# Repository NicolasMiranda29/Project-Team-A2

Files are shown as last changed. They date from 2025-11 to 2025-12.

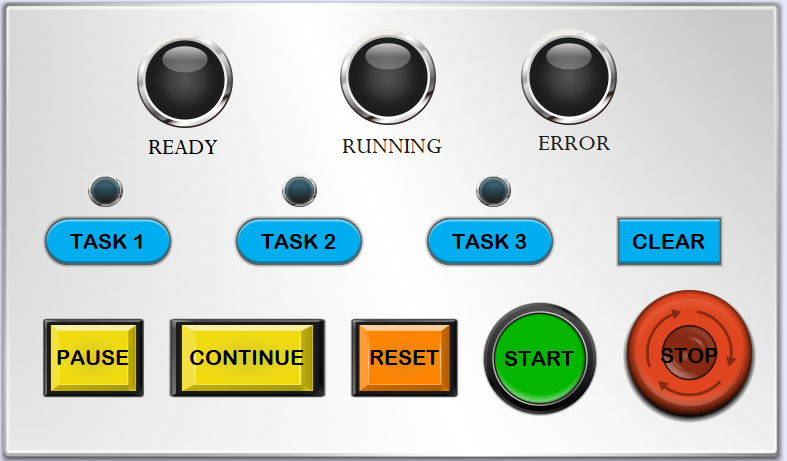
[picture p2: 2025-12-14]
INTRODUCTION TO ROBOTICS TUTORIAL/HMI/HMI_pic.png

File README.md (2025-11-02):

<h2> A2-Final Project 👩‍💻👩‍🔧👨‍💻👨‍🔧</h2>
In this section, you can see general details about two projects performed in the Robotics Lab by group A2.  
For more information, please click on the links of **"Introduction to Robotics"** and **"Introduction to Robotics Tutorial"**.

---

### Members

- **Juan Bogado** – Robot Programming  
- **Saul Ferreira** – Electrical Design  
- **Juan Chavez** – Mechanical Design  
- **Nicolas Miranda** – Documentation & Analysis

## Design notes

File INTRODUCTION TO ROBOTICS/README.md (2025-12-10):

# 🤖 PPP Robot: Port Crane-Style Prismatic Robot

This repository contains the kinematic and (optionally) dynamic models for a custom 3-DOF PPP robot with a port crane-style architecture and a two-finger gripper.

---

## 🧠 Robot Assumptions and Description

- **Type:** PPP (3 prismatic joints)
- **Structure:** Port crane-style configuration:
  - First axis (**Z**) translates along the **Y-axis** (vertical motion)
  - Second axis (**Y**) translates along the **X-axis** (horizontal motion)
  - Third axis (**X**) translates along the **Z-axis** (depth motion)

ROBOT ASSEMBLY PICTURE

**schematic diagram**



- **End-effector:** Two-finger gripper  
  > *Note: The gripper does not affect direct kinematics but may influence dynamics if its mass is modeled.*

---

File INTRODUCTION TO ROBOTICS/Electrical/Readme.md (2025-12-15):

#  **Part 4: Dynamic Analysis and Joint Torque Requirements**

Modeling Method
The dynamic modeling of the PPP Cartesian robot is carried out using a Newton–Euler formulation applied independently to each prismatic axis. Due to the orthogonal and decoupled structure of the Cartesian robot, coupling terms between axes are negligible, allowing each joint to be modeled as a translational mass subjected to inertial, gravitational, frictional, and external forces.
This approach is widely adopted in industrial gantry and Cartesian robots due to its computational simplicity and sufficient accuracy for actuator sizing

  Asumptions: 
	Payload: m_payload=5.00" kg" . \
	Extra assembly masses: m_z=6.00" kg" (Z carriage + screw + gripper), m_y=4.00" kg" (Y carriage & structure), m_x=2.00" kg" (X extras). \
	Linear maximum speeds: v_xy=0.50" m/s" (X & Y), v_z=0.20" m/s" (Z). \
	Accelerations: a_xy=1.00" " 〖"m/s" 〗^2, a_z=1.00" " 〖"m/s" 〗^2. \
	Pulley effective radius: r_p=0.020" m" (20 mm). \
	Ball-screw lead: "lead"=0.010" m/rev" (10 mm per rev). \
	Screw efficiency: η_screw=0.90. \ 
	Drive efficiency (belts/gear): η_drive=0.90. \
	Linear guide friction coefficient: μ=0.02. \
	Gravity: g=9.81" " 〖"m/s" 〗^2. \
	Safety factors: SF_XY=3.0for X/Y peaks; SF_Z=6.0for Z (holding + safety). \
\
The results of the calculations and results are shown in images

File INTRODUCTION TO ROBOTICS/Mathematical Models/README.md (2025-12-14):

## 📐 Direct Kinematic Model (DKM)

### 1. Input Variables

- `q1`: vertical displacement (Z-axis moving along Y)
- `q2`: horizontal displacement (Y-axis moving along X)
- `q3`: depth displacement (X-axis moving along Z)

### 2. End-Effector Position



### 3. Homogeneous Transformation Matrix

  

## 🔁 Inverse Kinematic Model (IKM)

Given a desired target point \((x_d, y_d, z_d)\), the required joint displacements are:



---

## 📊 Jacobian Matrix

The Jacobian relates joint velocities to the linear velocity of the end-effector:



---

## ⚙️ Dynamic Model 

For a simplified dynamic model (neglecting friction and coupling), using either the Newton-Euler or Lagrangian formulation:

Where:



### Simplified Example



## 📁 Folder Structure 
PPP_Robot/
├── README.md

├── main.m

├── gui_ppp_sim.m

├── ppp_fk.m

├── plot_ppp.m

├── animate_pick_and_place.m

├── move_to_position.m

├── ppp_dynamics.m

## Workspace


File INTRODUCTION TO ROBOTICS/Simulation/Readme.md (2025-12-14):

## Workspace


 ## Trajectory Simulation
 


 ## Path Simulation

 

# PPP Robot Simulation in MATLAB

## 📌 Project Overview
In this project, a **PPP-type robot** with a **port crane-style structure** was implemented using MATLAB.  
The project demonstrates kinematics, dynamics, visualization, and real-time control through a graphical interface.

---

## 📂 Folder Structure
The folder **`PPP_Robot_GUI`** contains the main functions:

- **`ppp_fk.m`** → Direct kinematics model  
- **`plot_ppp.m`** → Robot visualization  
- **`animate_pick_and_place.m`** → Example of a joint-space trajectory  
- **`ppp_dynamics.m`** → Simplified dynamic model  
- **`gui_ppp_sim.m`** → Graphical interface with sliders for real-time control  

---

## 🚀 Features
- Direct kinematics computation for PPP-type robot  
- Real-time visualization of robot motion  
- Example trajectory for pick-and-place tasks  
- Simplified dynamic modeling  
- Interactive GUI with sliders for intuitive control  

---

## ▶️ Usage
1. Clone or download this repository.  
2. Open MATLAB and navigate to the `PPP_Robot_GUI` folder.  
3. Run `gui_ppp_sim.m` to launch the graphical interface.  
4. Explore the other scripts for kinematics, dynamics, and trajectory examples.

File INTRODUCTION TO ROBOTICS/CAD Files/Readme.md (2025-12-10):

ROBOT ASSEMBLY PICTURE

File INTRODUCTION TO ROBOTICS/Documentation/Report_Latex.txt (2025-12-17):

\documentclass[12pt,a4paper]{report}
\usepackage{amsmath, amssymb, graphicx}
\usepackage{geometry}
\geometry{margin=2.5cm}
\usepackage{listings}
\usepackage{xcolor}
\usepackage{float}

% Estilo para mostrar código MATLAB
\lstdefinestyle{matlabstyle}{
  language=Matlab,
  backgroundcolor=\color{black!5},
  frame=single,
  framerule=0.6pt,
  basicstyle=\ttfamily\small,
  keywordstyle=\color{blue!60!black}\bfseries,
  commentstyle=\color{green!40!black}\itshape,
  stringstyle=\color{red!70!black},
  showstringspaces=false,
  breaklines=true,          % <-- corta las líneas largas automáticamente
  breakatwhitespace=true,   % <-- corta en espacios
  tabsize=2,
  captionpos=b
}

\begin{document}

\author{}
\date{}
\maketitle
\begin{titlepage}
    \centering
    \vspace*{1cm}

    % Logo institucional
    \includegraphics[width=0.8\textwidth]{Screenshot 2025-12-17 200551.png}\\[1cm] % Reemplaza 'logo.png' con el nombre de tu archivo

    % Título del proyecto
    {\Huge \textbf{PPP MANIPULATOR}}\\[0.5cm]
    {\Large Final Project Report}\\[2cm]

    % Curso y departamento
    {\large Introduction to Robotics}\\[0.3cm]
    {\large Mechanical Engineering}\\[0.3cm]
    {\large National University of Science and Technology}\\[2cm]

    % Integrantes
    {\large \textbf{Members:}}\\[0.5cm]
    {\large $\bullet$ Nicolas Miranda}\\
    {\large $\bullet$ Juan Bogado}\\
    {\large $\bullet$ Juan Chavez}\\
    {\large $\bullet$ Saul Ferreira}\\[2cm]

    % Supervisores
    {\large \textbf{Supervisors:}}\\[0.5cm]
    {\large $\bullet$ Liang Shuhao (Jason)}\\
    {\large $\bullet$ Marnel Patrick Junior Altius}\\

    \vfill
\end{titlepage}

\chapter*{Part 1: Introduction}

\section*{Application}
The difficulty of the project largely depends on its scope and intended application. Proper utilization of references and prior examples can significantly reduce the required effort, as they allow leveraging existing solutions and tested approaches. This project focuses on designing a practical, functional system that is simple enough for prototyping, yet demonstrates the core concepts effectively.

The system targets automated recycling classification using a PPP robot with a two-finger parallel gripper. It classifies small objects into three categories—metal, plastic, and paper—using cost-effective, non-vision sensors. Metal items are identified by an inductive proximity sensor, while plastic and paper are differentiated using a combination of capacitive dielectric sensing and mass measurement via a 5~kg load cell. All sensors are integrated into a fixed sensing station, which ensures stable distance, controlled grounding, low noise conditions, and repeatable force application, improving detection reliability during classification.

\section*{Robot Title and Type}
The robot, titled \textit{Automated Recycling Classifier (ARC)}, is a PPP Cartesian manipulator equipped with a two-finger parallel gripper. It employs three prismatic joints for translational motion along the X, Y, and Z axes. The use of a PPP configuration improves mechanical simplicity, supports straightforward simulation and kinematic modeling, and enables rapid prototype construction.

\section*{Problem and Task Description}
Manual sorting in recycling facilities is inefficient, inconsistent, and labor-dependent. This project automates the separation of materials by enabling the robot to pick items from the sensing zone, classify them, and deposit them into the correct bin. All detection takes place at the bench-mounted fixed sensing station, where the object's metallic response, dielectric properties, and mass are measured before sorting.

The inclusion of a load cell provides an additional physical parameter that improves robustness when distinguishing between paper and plastic, which often exhibit overlapping dielectric characteristics.

\section*{Functional and Performance Requirements}
The ARC robot must autonomously complete pick--classify--place cycles. Metal detection is executed using the inductive sensor. Plastic and paper differentiation is achieved through sensor fusion, combining capacitive dielectric measurements with mass data obtained from a 5~kg load cell mounted beneath the sensing platform. The classification process occurs at the fixed sensing station, ensuring repeatable positioning and consistent load application for reliable signal capture.

The gripper must handle objects of varying geometry without tool changes, and the system must consistently allocate objects into three output bins.

\subsection*{Performance Goals}
\begin{itemize}
    \item $\geq 90\%$ classification accuracy
    \item $\leq 5$ seconds per item cycle time
    \item End-effector repeatability within $\pm 2$~mm
    \item Support for object masses up to 5~kg, matching the load cell measurement range
\end{itemize}

\section*{Operating Environment and Constraints}
The platform is designed for benchtop operation without machine vision or external lighting. Objects must fit within the robot’s reachable workspace and be small enough for the parallel gripper. The fixed sensing station requires stable grounding, controlled contact force, and rigid mounting of the load cell to ensure accurate mass readings. Calibration of the capacitive sensor and load cell must be conducted prior to operation. Environmental factors such as humidity may influence dielectric measurements.

\subsection*{Constraints}
\begin{itemize}
    \item Inductive sensing limited exclusively to metal detection
    \item Capacitive readings sensitive to geometry, moisture, and surface area
    \item Load cell accuracy influenced by vibration and dynamic loading
    \item Limited detection capability for composite or multilayer materials
    \item Workspace constrained by PPP travel limits
\end{itemize}

\section*{Motivation}
The objective of the project is to demonstrate an affordable and compact robotic sorting system that improves sorting consistency while reducing manual labor. The integration of mass sensing enhances classification reliability without introducing complex vision systems. Automation in recycling environments reduces injuries, increases throughput stability, and enables scalable material handling at low operational cost. Institutions such as research labs, educational programs, and small recycling stations benefit directly from such a system.

\section*{Cost, Design, and Technical Constraints}
Because vision is excluded from the design, material identification relies on inductive sensing, capacitive dielectric measurement, and low-cost force-based mass estimation using a 5~kg load cell. The gripper must interface with all materials without custom attachments, and motion control must remain within safe velocity and acceleration boundaries. All decisions are made through real-time sensor readings processed by a controller.

Design considerations prioritize low-cost hardware for industrial application: inductive and capacitive sensors plus a load cell (combined cost $<$ USD~40), a PLC, and aluminum and stainless-steel structural materials. Technical limitations include sensor noise, dielectric overlap between materials, load cell drift, and inductive sensing limited to conductive metals.

\section*{Physical Assumptions Used in Modeling}
The manipulator is modeled assuming rigid-body links with negligible flex or structural deformation, enabling simplified dynamic evaluation. Prismatic joints are assumed to follow linear velocity trajectories without significant backlash or friction losses. The parallel gripper is modeled as capable of secure handling of objects up to 5~kg, without slippage under normal acceleration profiles.

The load cell is modeled as a linear elastic element with negligible hysteresis after calibration. Sensor outputs are considered deterministic once calibrated at the fixed station, allowing threshold-based classification and simple sensor fusion logic without probabilistic modeling at this stage.

\section*{Additional Considerations}
Future enhancements to the ARC platform may include machine vision for improved material recognition, machine learning-based adaptive classification combining dielectric and mass features, or increasing the number of detectable material categories. The integration of conveyor-based feed systems may also enable continuous, high-throughput sorting rather than batch-based processing. Optional end-effector-mounted force sensors could be explored to estimate mass during grasping, although this introduces additional complexity in control and dynamic compensation.

\section*{Overall Robot Diagram}
The ARC system consists of a PPP gantry structure with three linear axes, a parallel gripper, and a centralized fixed sensing station containing the inductive sensor, capacitive sensor, and a load-cell-based weighing platform. The microcontroller manages sensor fusion and classification logic, while the motion controller executes programmed trajectories. The processed items are sorted into three bins according to material classification.

\begin{figure}[H] % [h] = here, coloca la imagen en la posición actual
    \centering
    \includegraphics[width=0.8\textwidth]{Screenshot 2025-12-17 200027.png}
    \caption{CAD Drawings}
    \label{fig:robot}
\end{figure}

\begin{figure}[H]
    \centering
    \caption{Labeled robot diagram}
\end{figure}

\section*{Manipulator Workspace}
The operational workspace is defined by the gantry rails, forming a rectangular volume approximately 1000~mm $\times$ 650~mm $\times$ 410~mm. The fixed sensing station, weighing platform, and output bins are arranged within this envelope to reduce motion travel and maintain short cycle times. Objects are transported from the pick region to the sensing location, weighed and classified, and then routed to the appropriate disposal zone.

\section*{Design Specifications}
\subsection*{CAD Drawings}
All dimensions are in millimeters. The drawing scale is 4.9 relative to the robot used in this project.
\begin{figure}[H] % [h] = here, coloca la imagen en la posición actual
    \centering
    \includegraphics[width=0.8\textwidth]{Screenshot 2025-12-17 195749.png}
    \caption{CAD Drawings}
    \label{fig:robot}
\end{figure}

\begin{figure}[H] % [h] = here, coloca la imagen en la posición actual
    \centering
    \includegraphics[width=0.8\textwidth]{Screenshot 2025-12-17 195904.png}
    \caption{Cad File}
    \label{fig:robot}
\end{figure}

\chapter*{Part 2: Kinematic Structure}
\section*{Robot Joints and Kinematic Structure}
The robot is designed as a PPP manipulator, meaning it has three prismatic joints arranged orthogonally. This configuration enables simple translational motion in the three independent directions $(X, Y, Z)$, ensuring that the end-effector can reach any point within a rectangular workspace.

\subsection*{Reasoning for Design}
Three prismatic joints were selected because they provide the minimum degrees of freedom required for full translational positioning in 3D space. The absence of rotational joints simplifies kinematic equations, avoids singularities, and reduces control complexity. This structure is ideal for pick-and-place tasks, material handling, and environments where end-effector orientation is fixed or non-critical.

\section*{Joint Types, Axes, and Limits}
\begin{itemize}
    \item \textbf{Joint 1 ($q_1$):} Prismatic along the Y axis (vertical). Critical due to gravitational load. Typical limits: $q_1 \in [q_{1,\min}, q_{1,\max}]$.
    \item \textbf{Joint 2 ($q_2$):} Prismatic along the X axis (horizontal). Provides lateral positioning. Limits: $q_2 \in [q_{2,\min}, q_{2,\max}]$.
    \item \textbf{Joint 3 ($q_3$):} Prismatic along the Z axis (depth). Provides forward/backward positioning. Limits: $q_3 \in [q_{3,\min}, q_{3,\max}]$.
\end{itemize}

\section*{Forward Kinematic Model}
Frame assignments:
\begin{itemize}
    \item Base frame $\{0\}$ fixed at the origin.
    \item Frame $\{1\}$ translates along Y.
    \item Frame $\{2\}$ translates along X.
    \item Frame $\{3\}$ translates along Z.
    \item End-effector frame attached to the gripper.
\end{itemize}

\begin{figure}[H] % [h] = here, coloca la imagen en la posición actual
    \centering
    \includegraphics[width=0.8\textwidth]{Screenshot 2025-12-17 195458.png}
    \caption{Schematic Diagram}
    \label{fig:robot}
\end{figure}

The end-effector position is simply:
\[
    x = q_2, \quad y = q_1, \quad z = q_3.
\]

The homogeneous transformation from base to end-effector is:
\[
T_{0\,EE} =
\begin{bmatrix}
1 & 0 & 0 & q_2 \\
0 & 1 & 0 & q_1 \\
0 & 0 & 1 & q_3 \\
0 & 0 & 0 & 1
\end{bmatrix}.
\]

\section*{Modified DH Parameters}
Since this is a PPP robot:
\begin{itemize}
    \item All twist angles $\alpha_i = 0$.
    \item All link lengths $a_i = 0$.
    \item $\theta_i$ values are constant.
    \item $d_i$ corresponds to $q_1, q_2, q_3$.
\end{itemize}

\section*{Inverse Kinematic Model}
The IK is direct:
\[
q_1 = y_d, \quad q_2 = x_d, \quad q_3 = z_d.
\]

Joint limits must be satisfied:
\[
q_i \in [q_{i,\min}, q_{i,\max}].
\]

Velocity and acceleration limits:
\[
|\dot{q}_i| \le \dot{q}_{i,\max}, \qquad |\ddot{q}_i| \le \ddot{q}_{i,\max}.
\]

Gravity compensation on $q_1$ is recommended:
\[
F_{g,1} = m_{\mathrm{eff},1} g.
\]

\section*{Extended Inverse Kinematic (IK) Model}
For the PPP manipulator (three mutually orthogonal prismatic joints), the end-effector orientation is fixed and motion is purely translational. The IK solution is direct and exact.

\subsection*{Analytical Solution}
Given a desired Cartesian target position $(x_d, y_d, z_d)$ expressed in the base frame:
\[
q_1 = y_d, \qquad q_2 = x_d, \qquad q_3 = z_d.
\]
This yields an analytical, closed-form, globally valid solution with no singularities.

\subsection*{Joint Priorities and Physical Considerations}
\begin{itemize}
    \item \textbf{$q_1$ (vertical axis)}: Most critical due to gravitational load and safety. Requires smoother trajectories and torque/force considerations.
    \item \textbf{$q_2$ and $q_3$ (horizontal axes)}: Dynamically less restrictive; can sustain higher allowable velocities and accelerations.
    \item Joint priorities may be implemented through weighted objective functions in task-space or joint-space control.
\end{itemize}

\subsection*{IK Constraints}
\paragraph{Joint limits}
\[
q_1 \in [q_{1,\min}, q_{1,\max}], \qquad q_2 \in [q_{2,\min}, q_{2,\max}], \qquad q_3 \in [q_{3,\min}, q_{3,\max}].
\]
The target is feasible only if $(x_d, y_d, z_d)$ lies inside the rectangular parallelepiped defined by these limits.

\paragraph{Velocity and acceleration limits}
\[
|\dot{q}_i| \leq \dot{q}_{i,\max}, \qquad |\ddot{q}_i| \leq \ddot{q}_{i,\max}.
\]
These limits constrain the achievable trajectories during motion execution.

\paragraph{Collision and safety constraints} Avoid operating close to hard limits or obstacles; incorporate safe margins when generating trajectories.

\subsection*{Stability and Robustness Considerations}
\begin{itemize}
    \item \textbf{Filtering and anti-jitter}: Apply smoothing (e.g., low-pass filters or spline interpolation) to avoid abrupt changes caused by noise.
    \item \textbf{Soft saturations}: Use continuous saturation functions to prevent discontinuities when enforcing limits.
    \item \textbf{Task-space control stability}: Since $J$ is constant and full rank, a PID or PD controller with feedforward ensures practical stability.
    \item \textbf{Gravity compensation}: For the vertical joint,
    \[
    F_{g,1} = m_{\mathrm{eff},1} \cdot g,
    \]
    improves accuracy and reduces steady-state error.
\end{itemize}

\section*{Differential Kinematic Model}
The differential model relates joint velocities to Cartesian velocities of the end-effector.

Jacobian:
\[
J = \begin{bmatrix} 0 & 1 & 0 \\ 1 & 0 & 0 \\ 0 & 0 & 1 \end{bmatrix},
\qquad x=[x,y,z]^T,\quad q=[q_1,q_2,q_3]^T.
\]

Velocities:
\[
\dot{x} = J\, \dot{q}, \qquad \dot{q} = J^{-1}\dot{x}.
\]
Since $J$ is constant and full rank, inversion is stable.

Accelerations:
\[
\ddot{x} = J\, \ddot{q}.
\]
No $\dot{J}$ terms appear because $J$ is constant.

\subsection*{Differential Control with Priorities}
Weighted task-space mapping may be used with $W_x = \mathrm{diag}(w_x,w_y,w_z)$.

\subsection*{Limits and Stability}
Saturate $\dot{q}$ and $\ddot{q}$ to respect actuator limits. Constant full-rank $J$ ensures numerical stability.
Jacobian:
\[
J =
\begin{bmatrix}
0 & 1 & 0 \\
1 & 0 & 0 \\
0 & 0 & 1
\end{bmatrix}.
\]

Forward differential kinematics:
\[
\dot{x} = J \, \dot{q}.
\]

Inverse differential kinematics:
\[
\dot{q} = J^{-1} \dot{x}.
\]
Since $J$ is constant and full rank, the inversion is stable.

\chapter*{Part 3: Workspace Analysis}

\section*{Reachable vs Dexterous Workspace}
For the PPP robot, the reachable workspace is a rectangular parallelepiped defined by the maximum ranges of all three prismatic joints. Since the robot has no rotational joints, the end-effector orientation is fixed. Therefore, the dexterous workspace coincides with the reachable workspace, but without orientation freedom.

Analytically:
\[
x \in [0, Q_{2\max}], \quad y \in [0, Q_{1\max}], \quad z \in [0, Q_{3\max}].
\]
This produces a simple box-shaped workspace. 

\section*{Numerical Workspace Plot}
A numerical simulation confirms that the analytical workspace matches the computed workspace.

\begin{figure}[H] % [h] = here, coloca la imagen en la posición actual
    \centering
    \includegraphics[width=0.8\textwidth]{Screenshot 2025-12-17 195059.png}
    \caption{Workspace Plot}
    \label{fig:robot}
\end{figure}

\vspace{2\baselineskip} % deja 2 líneas en blanco

\section*{Jacobian-Based Singularity Identification}
The Jacobian is:
\[
J = 
\begin{bmatrix}
0 & 1 & 0 \\
1 & 0 & 0 \\
0 & 0 & 1
\end{bmatrix}.
\]
Since it is constant and full rank , no singularities occur.

\section*{Classification of Singularities}
A PPP robot has no internal singularities. Only mechanical limits at the boundaries restrict motion.

\section*{Workspace Limitations and Implications}
\begin{itemize}
  \item Rectangular workspace limited by joint ranges.
  \item No orientation freedom.
  \item Not suitable for orientation-dependent tasks.
  \item Well-suited for structured pick-and-place applications.
  \item Handling capacity depends on gripper geometry.
  \item Limited versatility due to absence of rotational DOF.
\end{itemize}

\chapter*{Part 4: Dynamic Analysis and Joint Torque Requirements}

\section*{Modeling Method}
The dynamic modeling of the PPP Cartesian robot is carried out using a Newton–Euler formulation applied independently to each prismatic axis. Due to the orthogonal and decoupled structure of the Cartesian robot, coupling terms between axes are negligible, allowing each joint to be modeled as a translational mass subjected to inertial, gravitational, frictional, and external forces.

This approach is widely adopted in industrial gantry and Cartesian robots due to its computational simplicity and sufficient accuracy for actuator sizing.

\section*{Full Dynamic Equation}
For each prismatic axis, the translational dynamic equation is expressed as:
\[
F_{\text{tot}} = m \cdot a + F_{\text{grav}} + F_{\text{fric}} + F_{\text{ext}}
\]
where:
\begin{itemize}
    \item $m$ is the equivalent moving mass including payload,
    \item $a$ is the linear acceleration,
    \item $F_{\text{grav}} = m \cdot g$ (only for the Z-axis),
    \item $F_{\text{fric}} = \mu \cdot m \cdot g$,
    \item $F_{\text{ext}}$ represents external process forces.
\end{itemize}

The required actuator torque is obtained from the total force using the drive kinematics:
\[
\tau = \frac{F_{\text{tot}} \cdot r_p}{\eta_{\text{drive}}} \quad \text{(belt-driven X and Y axes)}
\]
\[
\tau = \frac{F_{\text{tot}} \cdot L}{2\pi \cdot \eta_{\text{screw}}} \quad \text{(ball-screw-driven Z axis)}
\]
where $r_p$ is the pulley radius, $L$ is the screw lead, and $\eta$ is the transmission efficiency.

\section*{Gravity Torque Calculation (Z Axis)}
For the ball-screw lift axis:
\begin{enumerate}
    \item Moving mass: $m_Z = 11.00 \,\text{kg}$
    \item Gravity force: $F_{\text{grav}} = m_Z \cdot g = 11.00 \times 9.81 = 107.91 \,\text{N}$
    \item Acceleration force: $F_{\text{acc,Z}} = m_Z \cdot a_z = 11.00 \times 1.00 = 11.00 \,\text{N}$
    \item Total axial force: $F_{\text{tot,Z}} = 107.91 + 11.00 = 118.91 \,\text{N}$
    \item Screw torque:
    \[
    T_{\text{screw}} = \frac{F_{\text{tot,Z}} \cdot \text{lead}}{2\pi \cdot \eta_{\text{screw}}}
    = \frac{118.91 \times 0.010}{6.283 \times 0.90} \approx 0.210 \,\text{N·m}
    \]
    \item Motor torque (direct drive): $T_{\text{motor,Z}} \approx 0.210 \,\text{N·m}$
    \item Screw speed: $v_z/\text{lead} = 0.20/0.010 = 20.0 \,\text{rev/s} = 1200 \,\text{RPM}$
    \item Angular speed: $\omega = 2\pi \cdot 20.0 = 125.66 \,\text{rad/s}$
    \item Mechanical power: $P_{\text{motor,Z}} = T_{\text{motor,Z}} \cdot \omega \approx 26.4 \,\text{W}$
    \item With safety factor $SF_Z = 6$: $T_{\text{design,Z}} = 0.210 \times 6 = 1.26 \,\text{N·m}$
    \item Design-equivalent power: $P_{\text{design,Z}} = 1.26 \times 125.66 \approx 158.5 \,\text{W}$
\end{enumerate}

Thus, a servo in the 200–400 W range is appropriate for the Z axis.

\section*{Inertial Torque from Trajectory Motion (X Axis)}
For the belt-driven X axis:
\begin{enumerate}
    \item Acceleration force: $F_{\text{acc,X}} = m_X \cdot a_{xy} = 17.00 \times 1.00 = 17.00 \,\text{N}$
    \item Friction force: $F_{\text{fric,X}} = \mu \cdot m_X \cdot g = 0.02 \times (17.00 \times 9.81) = 3.34 \,\text{N}$
    \item Total force: $F_{\text{tot,X}} = 17.00 + 3.34 = 20.34 \,\text{N}$
    \item Pulley torque: $T_{\text{pulley,X}} = F_{\text{tot,X}} \cdot r_p = 20.34 \times 0.020 = 0.407 \,\text{N·m}$
    \item Motor torque: $T_{\text{motor,X}} = 0.407 / 0.90 \approx 0.452 \,\text{N·m}$
    \item Speed: $v_{xy}/(2\pi r_p) = 0.50/0.1257 \approx 3.98 \,\text{rev/s} = 238.7 \,\text{RPM}$
    \item Angular speed: $\omega = 25.0 \,\text{rad/s}$
    \item Mechanical power: $P_{\text{motor,X}} = 0.452 \times 25.0 \approx 11.3 \,\text{W}$
    \item With safety factor $SF_X = 3$: $T_{\text{peak,X}} = 0.452 \times 3 = 1.36 \,\text{N·m}$
\end{enumerate}

\section*{Inertial Torque from Trajectory Motion (Y Axis)}
For the belt-driven Y axis:
\begin{enumerate}
    \item Acceleration force: $F_{\text{acc,Y}} = m_Y \cdot a_{xy} = 15.00 \times 1.00 = 15.00 \,\text{N}$
    \item Friction force: $F_{\text{fric,Y}} = 0.02 \times (15.00 \times 9.81) = 2.94 \,\text{N}$
    \item Total force: $F_{\text{tot,Y}} = 15.00 + 2.94 = 17.94 \,\text{N}$
    \item Pulley torque: $T_{\text{pulley,Y}} = 17.94 \times 0.020 = 0.359 \,\text{N·m}$
    \item Motor torque: $T_{\text{motor,Y}} = 0.359 / 0.90 \approx 0.399 \,\text{N·m}$
    \item Speed: same as X axis, $238.7 \,\text{RPM}$, $\omega = 25.0 \,\text{rad/s}$
    \item Mechanical power: $P_{\text{motor,Y}} = 0.399 \times 25.0 \approx 9.97 \,\text{W}$
    \item With safety factor $SF_Y = 3$: $T_{\text{peak,Y}} = 0.399 \times 3 = 1.20 \,\text{N·m}$
\end{enumerate}

\section*{Payload and External Forces}
The payload mass is included in the equivalent moving mass of each axis.  
No additional external process forces are considered for pick-and-place operation.

\subsection*{Assumptions}
\begin{itemize}
    \item Payload: $m_{\text{payload}} = 5.00 \,\text{kg}$
    \item Extra assembly masses: $m_z = 6.00 \,\text{kg}$ (Z carriage + screw + gripper), $m_y = 4.00 \,\text{kg}$ (Y carriage \& structure), $m_x = 2.00 \,\text{kg}$ (X extras)
    \item Linear maximum speeds: $v_{xy} = 0.50 \,\text{m/s}$ (X \& Y), $v_z = 0.20 \,\text{m/s}$ (Z)
    \item Accelerations: $a_{xy} = 1.00 \,\text{m/s}^2$, $a_z = 1.00 \,\text{m/s}^2$
    \item Pulley effective radius: $r_p = 0.020 \,\text{m}$ (20 mm)
    \item Ball-screw lead: $\text{lead} = 0.010 \,\text{m/rev}$ (10 mm per rev)
    \item Screw efficiency: $\eta_{\text{screw}} = 0.90$
    \item Drive efficiency (belts/gear): $\eta_{\text{drive}} = 0.90$
    \item Linear guide friction coefficient: $\mu = 0.02$
    \item Gravity: $g = 9.81 \,\text{m/s}^2$
    \item Safety factors: $SF_{XY} = 3.0$ for X/Y peaks; $SF_Z = 6.0$ for Z (holding + safety)
    \item Workspace: $X = 1.000 \,\text{m}, Y = 0.610 \,\text{m}, Z = 0.410 \,\text{m}$
\end{itemize}

\subsection*{Notation \& Formulas}
\[
F_{\text{acc}} = m \cdot a, \quad
F_{\text{fric}} = \mu \cdot m \cdot g, \quad
F_{\text{tot}} = F_{\text{acc}} + F_{\text{fric}}
\]
\[
T_{\text{pulley}} = F_{\text{tot}} \cdot r_p, \quad
T_{\text{motor}} = \frac{T_{\text{pulley}}}{\eta_{\text{drive}}}
\]
\[
T_{\text{screw}} = \frac{F_{\text{tot}} \cdot \text{lead}}{2\pi \cdot \eta_{\text{screw}}}
\]
\[
\text{rev/s} = \frac{v}{2\pi r_p}, \quad \text{RPM} = \text{rev/s} \cdot 60, \quad
\omega = 2\pi \cdot \text{rev/s}
\]
\[
P = T \cdot \omega, \quad
T_{\text{design}} = T_{\text{motor}} \cdot SF
\]

\subsection*{Step-by-Step Numeric Calculations}
Masses each axis must move:
\[
m_Z = m_{\text{payload}} + m_z = 5.00 + 6.00 = 11.00 \,\text{kg}
\]
\[
m_Y = m_{\text{payload}} + m_z + m_y = 5.00 + 6.00 + 4.00 = 15.00 \,\text{kg}
\]
\[
m_X = m_{\text{payload}} + m_z + m_y + m_x = 5.00 + 6.00 + 4.00 + 2.00 = 17.00 \,\text{kg}
\]

\section*{Maximum Required Joint Torque Determination}
From Sections 4.3 and 4.4, the maximum continuous torque requirements are:
\[
T_{\text{motor,X}} = 0.452 \,\text{N·m}, \quad
T_{\text{motor,Y}} = 0.399 \,\text{N·m}, \quad
T_{\text{motor,Z}} = 0.210 \,\text{N·m}
\]

\section*{Safety Factor for Actuator Sizing}
\[
T_{\text{design}} = T_{\text{max}} \cdot SF
\]
\begin{itemize}
    \item For X and Y axis, $SF = 3$
    \item For Z axis, $SF = 6$
\end{itemize}
\[
T_{\text{design,X}} = 1.36 \,\text{N·m}, \quad
T_{\text{design,Y}} = 1.20 \,\text{N·m}, \quad
T_{\text{design,Z}} = 1.26 \,\text{N·m}
\]

\section*{Torque Tables and Plots}
\begin{table}[H] % [H] fuerza la posición exacta
\centering
\caption{Torque requirements and selected motors}
\begin{tabular}{|c|c|c|c|}
\hline
Axis & Continuous Torque (N·m) & Design Torque (N·m) & Selected Motor \\
\hline
X & 0.45 & 1.36 & 750 W servo \\
Y & 0.40 & 1.20 & 400 W servo \\
Z & 0.21 & 1.26 & 750 W servo \\
\hline
\end{tabular}
\end{table}

\begin{figure}[H] % [h] = here, coloca la imagen en la posición actual
    \centering
    \includegraphics[width=0.7\textwidth]{Screenshot 2025-12-17 192806.png}
    \caption{Torque vs. Time}
    \label{fig:robot}
\end{figure}

\begin{figure}[H] % [h] = here, coloca la imagen en la posición actual
    \centering
    \includegraphics[width=0.7\textwidth]{Screenshot 2025-12-17 193152.png}
    \caption{Speed-Torque curve.}
    \label{fig:robot}
\end{figure}

\section*{Components \& Design}

\subsection*{Main Controller}
\begin{itemize}
    \item Siemens S7-1200 PLC
    \item Model: CPU 1212C AC/DC/Relay (6ES7212-1HE40-0XB0)
    \item 8 DI, 6 DO, expandable
    \item Reliable for industrial environment
    \item Expansion for Stepper/Servo Control (PTO Outputs)
    \item Siemens Signal Board SB 1231 (if extra AI required)
    \item Siemens Pulse-train module not required → CPU1212C already supports PTO up to 100 kHz
\end{itemize}

\subsection*{Servo Motors + Drivers (PPP Axes)}
Payload 5 kg + 1 m horizontal travel requires servo motors, not steppers.
\begin{itemize}
    \item \textbf{X Axis (1 m travel)}  
    Servo motor: Delta ECMA-C20807RS (750 W, 3000 rpm)  
    Driver: Delta ASDA-B2 series (Model: ASD-B2-0721-B)  
    Transmission: HTD 5M belt, 25 mm wide OR ballscrew SFU1610
    \item \textbf{Y Axis (1 m travel)}  
    Servo motor: Delta ECMA-C20604RS (400 W)  
    Driver: Delta ASD-B2-0421-B (400 W driver)  
    Transmission: HTD 5M belt, 20–25 mm width
    \item \textbf{Z Axis (0.8–1 m vertical travel)}  
    Servo motor: Delta ECMA-C20807RS (750 W)  
    Driver: Delta ASD-B2-0721-B  
    Transmission: Ballscrew SFU1610 with BK/BF supports + linear guides
\end{itemize}

\subsection*{Linear Motion Components}
\begin{itemize}
    \item Linear Guides: Hiwin HGR20 rails (20 mm width)
    \item Blocks: HGW20CC (4 per axis)
    \item Ballscrews: SFU1610 (16 mm dia, 10 mm pitch) for Z; SFU1605 or HTD 5M belt drive for X \& Y
\end{itemize}

\subsection*{Sensors for Material Classification}
\begin{itemize}
    \item \textbf{Metal Detection}: Inductive sensor LJ12A3-4-Z/BX, PNP Normally Open, 10–30 VDC
    \item \textbf{Plastic vs Paper Detection}: Capacitive sensor LJC18A3-B-Z/BX, PNP Normally Open, 10–30 VDC
    \item \textbf{Weight Measurement}: Load cell 5 kg aluminum plate, amplifier Waveshare 0–10 V output, connected to PLC AI0
\end{itemize}

\subsection*{Gripper (Pneumatic)}
\begin{itemize}
    \item Parallel Pneumatic Gripper: SMC MHZ2-20D
    \item Solenoid Valve: SMC SY3120-5LZD-01, 24 VDC, 3-way single solenoid
    \item Pneumatic Air Preparation: SMC AF20-N02 (filter), SMC AR20-N02 (regulator)
\end{itemize}

\subsection*{Power Supply System}
\begin{itemize}
    \item For PLC, sensors, valves (24 VDC bus): Meanwell LRS-350-24, 24 V, 14.6 A
    \item For servo drives (48 VDC bus): Meanwell RSP-750-48, 48 V, 60 A
    \item For load cell amplifier: same 24 V bus (accepts 12–24 V)
\end{itemize}

\subsection*{Safety Components}
\begin{itemize}
    \item Main Breaker: Schneider GV2-ME10 (adjustable 6–10 A)
    \item Emergency Stop: Schneider XALK178 mushroom E-stop
    \item Fuses: 5×20 mm fuse holders, 3A fuse for 24V logic, 10–15A fuse for servo power input
    \item Surge \& Noise Protection: Ferrite cores on all servo cables, EMI filter Schaffner FN2070-10-06
\end{itemize}

\subsection*{Cables \& Wiring}
\begin{itemize}
    \item Servo Motor Power Cables: 4-core shielded, 2.5 mm² (750 W), 1.5 mm² (400 W), length 8–10 m per axis
    \item Encoder/Signal Cables: 6-core shielded twisted pair, 0.5–0.75 mm², 10 m per axis
    \item Sensor Cables: 3-wire shielded, 0.5 mm², 5–10 m
    \item PLC Wiring: Single core 0.75 mm² for DO/DI and 24V distribution
\end{itemize}

\subsection*{Electrical Enclosure Components}
\begin{itemize}
    \item Metal enclosure 600×400×200 mm (steel)
    \item DIN rails (2× 350 mm)
    \item Cable ducts
    \item 24VDC terminal blocks (Weidmüller)
    \item Grounding bar
    \item Cooling fan 120 mm + filter
\end{itemize}

\section*{Wiring Diagram}

\begin{figure}[H] % [h] = here, coloca la imagen en la posición actual
    \centering
    \includegraphics[width=0.9\textwidth]{Screenshot 2025-12-17 193501.png}
    \caption{Wiring Diagram.}
    \label{fig:robot}
\end{figure}

\section*{PLC Configuration}

\subsection*{DI Tags}
\begin{itemize}
    \item I0.0 \quad X\_MINMAX
    \item I0.1 \quad Y\_MINMAX
    \item I0.2 \quad Z\_MINMAX
    \item I0.5 \quad METAL\_IND
    \item I0.6 \quad CAP\_HIGH
\end{itemize}

\subsection*{DO Tags}
\begin{itemize}
    \item Q0.0 \quad SERVO\_ENABLE X
    \item Q0.1 \quad SERVO\_ENABLE Y
    \item Q0.2 \quad SERVO\_ENABLE Z
    \item Q0.3 \quad GRIPPER\_OC
    \item Q0.4 \quad COIL\_CONTACTOR
    \item Q0.5 \quad TOWER\_RED
    \item Q0.6 \quad TOWER\_YELLOW
    \item Q0.7 \quad TOWER\_GREEN
\end{itemize}

\subsection*{AI Tag}
\begin{itemize}
    \item AI0 \quad WEIGHT\_mA \quad (scale 4--20 mA $\rightarrow$ 0..FULL\_SCALE grams)
\end{itemize}

\subsection*{PROFINET Drive Tags}
\textbf{DriveX}
\begin{itemize}
    \item DriveX.ControlWord
    \item DriveX.TargetPosition
    \item DriveX.TargetVelocity
    \item DriveX.StatusWord
    \item DriveX.ActualPosition
    \item DriveX.ErrorCode
\end{itemize}

\textbf{DriveY}
\begin{itemize}
    \item DriveY.ControlWord
    \item DriveY.TargetPosition
    \item DriveY.TargetVelocity
    \item DriveY.StatusWord
    \item DriveY.ActualPosition
    \item DriveY.ErrorCode
\end{itemize}

\textbf{DriveZ}
\begin{itemize}
    \item DriveZ.ControlWord
    \item DriveZ.TargetPosition
    \item DriveZ.TargetVelocity
    \item DriveZ.StatusWord
    \item DriveZ.ActualPosition
    \item DriveZ.ErrorCode
\end{itemize}

\section*{PLC Logic Chart}

\begin{figure}[H] % [h] = here, coloca la imagen en la posición actual
    \centering
    \includegraphics[width=0.8\textwidth]{Screenshot 2025-12-17 193801.png}
    \caption{PLC Logic Chart}
    \label{fig:robot}
\end{figure}

\begin{figure}[H] % [h] = here, coloca la imagen en la posición actual
    \centering
    \includegraphics[width=0.8\textwidth]{Screenshot 2025-12-17 194027.png}
    \caption{PLC Logic Chart}
    \label{fig:robot}
\end{figure}

\chapter*{Part 5: Trajectory Generation Techniques}

\section*{Project Overview}
A PPP robot was implemented in MATLAB and Simulink. The folder \texttt{PPP\_Robot\_GUI} contains the key files: 

\begin{itemize}
    \item \texttt{ppp\_fk.m}: forward kinematics
    \item \texttt{plot\_ppp.m}: visualization
    \item \texttt{animate\_pick\_and\_place.m}: joint-space trajectory example
    \item \texttt{ppp\_dynamics.m}: simplified dynamics
    \item \texttt{gui\_ppp\_sim.m}: real-time control GUI
\end{itemize}

\section*{Joint-Space Trajectories}
Interpolated trajectories in $q_1, q_2, q_3$ were implemented in \texttt{animate\_pick\_and\_place.m}, producing non-linear Cartesian paths.
\noindent\textbf{MATLAB animate\_pick\_and\_place.m}
\begin{lstlisting}[style=matlabstyle, caption={MATLAB ppp\_fk.m}]
function T = ppp_fk(q)
    % Cinemática directa para robot PPP tipo grúa
    % q = [q1; q2; q3] → desplazamientos prismáticos

    x = q(2); % eje Y moviéndose en X
    y = q(1); % eje Z moviéndose en Y
    z = q(3); % eje X moviéndose en Z

    T = [eye(3), [x; y; z]; 0 0 0 1];
end
\end{lstlisting}

\section*{Task-space trajectories}

\begin{figure}[H] % [h] = here, coloca la imagen en la posición actual
    \centering
    \includegraphics[width=0.8\textwidth]{Screenshot 2025-12-17 194311.png}
    \caption{Task-space trajectories}
    \label{fig:robot}
\end{figure}

\section*{Real-Time Trajectory Generation}
The GUI allows real-time modification of $q_1, q_2, q_3$, demonstrating interactive trajectory generation.
\begin{figure}[H] % [h] = here, coloca la imagen en la posición actual
    \centering
    \includegraphics[width=0.8\textwidth]{Screenshot 2025-12-17 194453.png}
    \caption{Task-space trajectories}
    \label{fig:robot}
\end{figure}

\vspace{2\baselineskip} % deja 2 líneas en blanco
\vspace{2\baselineskip} % deja 2 líneas en blanco

\begin{lstlisting}[style=matlabstyle, caption={MATLAB gui\_ppp\_sim.m}]
function gui_ppp_sim()
    f = figure('Name','Simulador Robot PPP','Color','k','Position',[100 100 800 600]);

    % Sliders para q1, q2, q3
    uicontrol(f,'Style','text','String','q1 (Y vertical)',...
        'Position',[20 550 100 20],'ForegroundColor','w','BackgroundColor','k');
    s1 = uicontrol(f,'Style','slider','Min',0,'Max',1,'Value',0.2,...
        'Position',[130 550 200 20],'Callback',@update_plot);

    uicontrol(f,'Style','text','String','q2 (X horizontal)',...
        'Position',[20 520 100 20],'ForegroundColor','w','BackgroundColor','k');
    s2 = uicontrol(f,'Style','slider','Min',0,'Max',1,'Value',0.5,...
        'Position',[130 520 200 20],'Callback',@update_plot);

    uicontrol(f,'Style','text','String','q3 (Z profundidad)',...
        'Position',[20 490 100 20],'ForegroundColor','w','BackgroundColor','k');
    s3 = uicontrol(f,'Style','slider','Min',0,'Max',1,'Value',0.3,...
        'Position',[130 490 200 20],'Callback',@update_plot);

    % Botón de animación
    uicontrol(f,'Style','pushbutton','String','Animar Pick & Place',...
        'Position',[600 550 150 30],'Callback',@(src,event) animate_pick_and_place());

    % Ejes de visualización
    ax = axes('Parent',f,'Position',[0.4 0.1 0.55 0.75]);
    set(ax,'Color','k');
    view(3); axis equal; grid on;
    xlabel('X'); ylabel('Y'); zlabel('Z');

    % Función de actualización
    function update_plot(~,~)
        q = [s1.Value; s2.Value; s3.Value];
        axes(ax);
        plot_ppp(q, 'c');
    end

    update_plot();
end
\end{lstlisting}
\vspace{2cm} % baja 1 cm
\begin{lstlisting}[style=matlabstyle, caption={MATLAB plot\_ppp.m}]
function plot_ppp(q, color)
    % Visualiza el robot PPP en configuración q
    T = ppp_fk(q);
    pos = T(1:3,4);

    clf; hold on; axis equal;
    set(gcf,'Color','k'); % fondo negro
    xlabel('X'); ylabel('Y'); zlabel('Z');
    view(3); grid on;

    % Ejes base
    plot3(0,0,0,'wo','MarkerSize',6,'LineWidth',2);
    % Trayectoria de cada eje
    plot3([0 q(2)], [0 0], [0 0], 'r', 'LineWidth', 2); % eje Y → X
    plot3([q(2) q(2)], [0 q(1)], [0 0], 'g', 'LineWidth', 2); % eje Z → Y
    plot3([q(2) q(2)], [q(1) q(1)], [0 q(3)], 'b', 'LineWidth', 2); % eje X → Z

    % End-effector
    plot3(pos(1), pos(2), pos(3), 'mo', 'MarkerSize', 8, 'LineWidth', 2);
end
\end{lstlisting}

\section*{Task-Space Trajectories}
Using \texttt{ppp\_fk.m}, Cartesian paths $(x,y,z)$ are mapped into joint space for linear or curved workspace paths.
\begin{lstlisting}[style=matlabstyle, caption={MATLAB ppp\_fk.m}]
function T = ppp_fk(q)
    % Cinemática directa para robot PPP tipo grúa
    % q = [q1; q2; q3] → desplazamientos prismáticos

    x = q(2); % eje Y moviéndose en X
    y = q(1); % eje Z moviéndose en Y
    z = q(3); % eje X moviéndose en Z

    T = [eye(3), [x; y; z]; 0 0 0 1];
end
\end{lstlisting}

\vspace{2cm} % baja 1 cm

\section*{Trajectory Constraints}
Velocity, acceleration, and workspace limits can be enforced during interpolation.
\begin{lstlisting}[style=matlabstyle, caption={MATLAB ppp\_dynamics.m}]
function tau = ppp_dynamics(q, dq, ddq, m)
    % Modelo dinámico simplificado
    g = 9.81;
    M = diag(m); % matriz de inercia
    G = [m(1)*g; 0; 0]; % gravedad solo en eje vertical
    C = zeros(3,1); % sin Coriolis

    tau = M * ddq + C + G;
end
\end{lstlisting}

\section*{Discussion of Methods}
\begin{itemize}
    \item Joint-space: simple, but produces curved Cartesian paths.
    \item Task-space: intuitive, but requires IK.
    \item Real-time: ideal for testing and interactive control.
\end{itemize}

\chapter*{Part 6: Conclusion}

\section*{Overall System Evaluation}
The Automated Recycling Classifier (ARC) system successfully demonstrates the feasibility of using a
low-cost PPP Cartesian robot combined with non-vision sensors for material classification in a
benchtop recycling application. The integration of inductive sensing, capacitive dielectric
measurement, and load-cell-based mass evaluation provides a sensor fusion approach capable of
distinguishing metal, plastic, and paper with acceptable reliability under controlled conditions.
The use of a fixed sensing station proved critical in reducing variability caused by distance, grounding
effects, vibration, and dynamic loading. This design choice resulted in improved repeatability and
signal consistency across classification cycles. The PPP gantry configuration offered mechanical
simplicity, predictable kinematics, and ease of control, aligning well with the project objectives of
affordability, modularity, and ease of implementation.
While the system is not intended for industrial-scale throughput or complex material mixtures, it
effectively fulfills its role as a compact automated sorting demonstrator and educational prototype.

\section*{Recommendations}
\begin{itemize}
    \item Implement signal filtering and averaging techniques to reduce sensor noise and improve capacitive and load cell measurement stability.
    \item Introduce calibration routines for the capacitive sensor and load cell to compensate for environmental variations such as humidity and temperature.
    \item Improve mechanical isolation of the weighing platform to minimize vibration-induced measurement errors.
    \item Explore adaptive thresholding or simple machine learning classifiers to enhance plastic–paper differentiation.
    \item Consider modular mechanical design upgrades to allow easy scaling of workspace dimensions or payload capacity.
\end{itemize}

\section*{Summary of Results}
\begin{itemize}
    \item Reliable execution of autonomous pick--classify--place cycles within the defined workspace was achieved.
    \item Metal objects were consistently detected using the inductive proximity sensor.
    \item Plastic and paper materials were differentiated using a combination of dielectric sensing and mass measurement.
    \item Stable and repeatable classification was demonstrated at a fixed sensing station.
    \item Effective integration of low-cost, non-vision sensors was achieved without compromising system functionality.
\end{itemize}

\section*{Suitability for Intended Application}
The ARC platform is well suited for its intended application as a benchtop automated recycling
classifier and proof-of-concept system. It addresses limitations associated with manual sorting by
improving consistency, reducing human involvement, and enabling repeatable material classification
using affordable hardware.
Although the system is not designed for high-speed industrial recycling lines or complex composite
materials, it is highly appropriate for educational and research environments, small-scale recycling
demonstrations, and prototype development or sensor evaluation platforms. Its low cost, compact
footprint, and straightforward control architecture make it a practical solution for controlled sorting
scenarios.

\section*{Final Design Justification}
The final ARC system design is justified by its strong alignment with the project objectives of
affordability, simplicity, and functional effectiveness. The use of a PPP Cartesian manipulator ensures
predictable motion, ease of simulation, and low mechanical complexity. Employing non-vision sensors
significantly reduces system cost and computational requirements while maintaining acceptable
classification performance under controlled conditions.
The fixed sensing station design addresses key challenges related to measurement repeatability and
sensor stability, enabling reliable sensor fusion. Overall, the final design represents a well-balanced
compromise between performance, cost, and technical complexity, making it a suitable and
defensible solution for automated recycling classification at the prototype level.

\end{document}

## Joint-space trajectories
The trajectories were defined directly in the joint variables q1, q2, q3. En el código **animate_pick_and_place.m**, se implementó un movimiento interpolado entre posiciones iniciales y finales. Esto permite observar cómo el robot realiza una operación pick‑and‑place en el espacio articular.

## Task-space trajectories
foto

Task-space trajectories were defined in Cartesian coordinates (x, y, z) of the end-effector. The function **ppp_fk.m** converts these trajectories into joint coordinates, allowing the generation of linear or curved motions within the workspace.

## Real-time trajectory generation
foto

The interface **gui_ppp_sim.m** allows real-time modification of q1, q2, and q3 through sliders. This provides a direct example of real-time trajectory generation, where the user interacts with the robot and observes the immediate response in the simulation.

## Trajectory constraints
Constraints on velocity, acceleration, and workspace limits can be integrated into the animation functions. For example, limiting the vertical displacement q1 to prevent the robot from crossing the ground, or applying maximum velocity limits to the interpolation profiles.

## Discussion of chosen trajectory method
2 fotos

In this project, three approaches were compared:
- **Joint-space trajectories**: simpler to implement but generate nonlinear paths in Cartesian space.
- **Task-space trajectories**: more intuitive for pick-and-place tasks but require solving inverse kinematics.
- **Real-time generation**: useful for interactive simulations through the GUI.

The choice of method depends on the application: for simple movements, joint-space trajectories are recommended; for precise manipulation tasks, Cartesian trajectories are preferable.

Joint-space trajectories
The trajectories were defined directly in the joint variables q1, q2, and q3. In the file **animate_pick_and_place.m**, an interpolated motion between initial and final joint positions was implemented. This allows visualization of how the robot executes a pick‑and‑place sequence entirely in joint space.

Task‑space trajectories
foto

A second approach consisted of defining trajectories in Cartesian space (x, y, z). The function **ppp_fk.m** is used to convert these Cartesian paths into the corresponding joint positions through the inverse kinematics relation. Using task‑space trajectories allows the generation of linear or curved motions in the workspace, which are more intuitive for manipulation tasks.

Real‑time trajectory generation
foto

The interface **gui_ppp_sim.m** enables real‑time modification of q1, q2, and q3 using sliders. This constitutes an example of real‑time trajectory generation, where the user directly interacts with the robot and observes the immediate effect on the simulated model.

Trajectory constraints
Constraints on velocity, acceleration, and workspace limits can be integrated into the animation functions. For example, limiting vertical displacement q1 to prevent ground collision, or imposing maximum velocity limits on the interpolation profiles.

Discussion of chosen trajectory methods
2 fotos

Three trajectory-generation approaches were compared in this project:
• Joint‑space trajectories: simple to implement but produce nonlinear Cartesian paths.
• Task‑space trajectories: more intuitive for manipulation but require inverse kinematics.
• Real‑time trajectory generation: ideal for interactive simulations or rapid prototyping using the GUI.

The selection of the trajectory method depends on the application. For simple or repetitive motions, joint‑space trajectories are recommended. For precise manipulation in structured environments (e.g., pick‑and‑place), task‑space trajectories are generally preferable.

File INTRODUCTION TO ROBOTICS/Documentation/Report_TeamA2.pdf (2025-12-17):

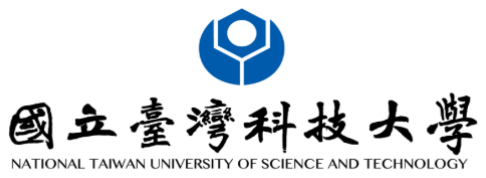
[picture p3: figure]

# PPP MANIPULATOR

## Final Project Report

### Introduction to Robotics

### Mechanical Engineering

### National University of Science and Technology

### Members:

### - Nicolas Miranda - Juan Bogado - Juan Chavez - Saul Ferreira

### Supervisors:

### - Liang Shuhao (Jason) - Marnel Patrick Junior Altius

# Part 1: Introduction

## Application

The difficulty of the project largely depends on its scope and intended application. Proper utilization of references and prior examples can significantly reduce the required effort, as they allow leveraging existing solutions and tested approaches. This project focuses on designing a practical, functional system that is simple enough for prototyping, yet demonstrates the core concepts effectively.
The system targets automated recycling classification using a PPP robot with a two-finger parallel gripper. It classifies small objects into three categories—metal, plastic, and paper—using cost-effective, non-vision sensors. Metal items are identified by an inductive proximity sensor, while plastic and paper are differentiated using a combination of capacitive dielectric sensing and mass measurement via a 5 kg load cell. All sensors are integrated into a fixed sensing station, which ensures stable distance, controlled grounding, low noise conditions, and repeatable force application, improving detection reliability during classification.

## Robot Title and Type

The robot, titled Automated Recycling Classifier (ARC), is a PPP Cartesian manipulator equipped with a two-finger parallel gripper. It employs three prismatic joints for translational motion along the X, Y, and Z axes. The use of a PPP configuration improves mechanical simplicity, supports straightforward simulation and kinematic modeling, and enables rapid prototype construction.

## Problem and Task Description

Manual sorting in recycling facilities is inefficient, inconsistent, and labor-dependent. This project automates the separation of materials by enabling the robot to pick items from the sensing zone, classify them, and deposit them into the correct bin. All detection takes place at the bench-mounted fixed sensing station, where the object’s metallic response, dielectric properties, and mass are measured before sorting.
The inclusion of a load cell provides an additional physical parameter that improves robustness when distinguishing between paper and plastic, which often exhibit overlapping dielectric characteristics.

## Functional and Performance Requirements

The ARC robot must autonomously complete pick–classify–place cycles. Metal detection is executed using the inductive sensor. Plastic and paper differentiation is achieved through sensor fusion, combining capacitive dielectric measurements with mass data obtained from a 5 kg load cell mounted beneath the sensing platform. The classification process occurs at the fixed sensing station, ensuring repeatable positioning and consistent load application for reliable signal capture.
The gripper must handle objects of varying geometry without tool changes, and the system must consistently allocate objects into three output bins.

### Performance Goals

- ≥ 90% classification accuracy
- ≤ 5 seconds per item cycle time
- End-effector repeatability within ±2 mm
- Support for object masses up to 5 kg, matching the load cell measurement range

## Operating Environment and Constraints

The platform is designed for benchtop operation without machine vision or external lighting. Objects must fit within the robot’s reachable workspace and be small enough for the parallel gripper. The fixed sensing station requires stable grounding, controlled contact force, and rigid mounting of the load cell to ensure accurate mass readings. Calibration of the capacitive sensor and load cell must be conducted prior to operation. Environmental factors such as humidity may influence dielectric measurements.

### Constraints

- Inductive sensing limited exclusively to metal detection
- Capacitive readings sensitive to geometry, moisture, and surface area
- Load cell accuracy influenced by vibration and dynamic loading
- Limited detection capability for composite or multilayer materials
- Workspace constrained by PPP travel limits

## Motivation

The objective of the project is to demonstrate an affordable and compact robotic sorting system that improves sorting consistency while reducing manual labor. The integration of mass sensing enhances classification reliability without introducing complex vision systems. Automation in recycling environments reduces injuries, increases throughput stability, and enables scalable material handling at low operational cost. Institutions such as research labs, educational programs, and small recycling stations benefit directly from such a system.

## Cost, Design, and Technical Constraints

Because vision is excluded from the design, material identification relies on inductive sensing, capacitive dielectric measurement, and low-cost force-based mass estimation using a 5 kg load cell. The gripper must interface with all materials without custom attachments, and motion control must remain within safe velocity and acceleration boundaries. All decisions are made through real-time sensor readings processed by a controller.
Design considerations prioritize low-cost hardware for industrial application: inductive and capacitive sensors plus a load cell (combined cost < USD 40), a PLC, and aluminum and stainless-steel structural materials. Technical limitations include sensor noise, dielectric overlap between materials, load cell drift, and inductive sensing limited to conductive metals.

## Physical Assumptions Used in Modeling

The manipulator is modeled assuming rigid-body links with negligible flex or structural deformation, enabling simplified dynamic evaluation. Prismatic joints are assumed to follow linear velocity trajectories without significant backlash or friction losses. The parallel gripper is modeled as capable of secure handling of objects up to 5 kg, without slippage under normal acceleration profiles.
The load cell is modeled as a linear elastic element with negligible hysteresis after calibration. Sensor outputs are considered deterministic once calibrated at the fixed station, allowing threshold-based classification and simple sensor fusion logic without probabilistic modeling at this stage.

## Additional Considerations

Future enhancements to the ARC platform may include machine vision for improved material recognition, machine learning-based adaptive classification combining dielectric and mass features, or increasing the number of detectable material categories. The integration of conveyor-based feed systems may also enable continuous, high-throughput sorting rather than batch-based processing. Optional end-effector-mounted force sensors could be explored to estimate mass during grasping, although this introduces additional complexity in control and dynamic compensation.

## Overall Robot Diagram

The ARC system consists of a PPP gantry structure with three linear axes, a parallel gripper, and a centralized fixed sensing station containing the inductive sensor, capacitive sensor, and a load-cell-based weighing platform. The microcontroller manages sensor fusion and classification logic, while the motion controller executes programmed trajectories. The processed items are sorted into three bins according to material classification.

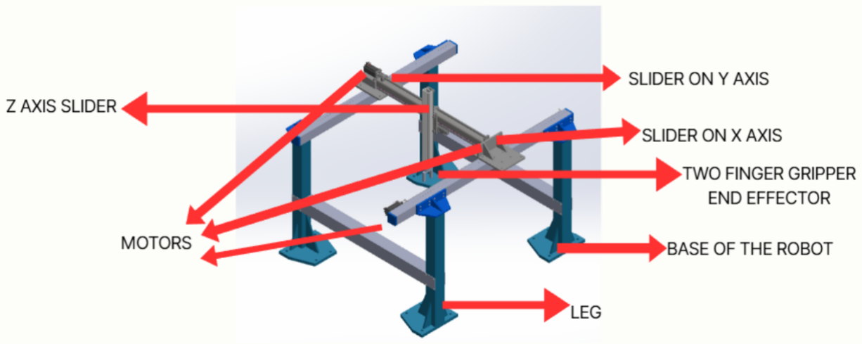
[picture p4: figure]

Figure 1: CAD Drawings

Figure 2: Labeled robot diagram

## Manipulator Workspace

The operational workspace is defined by the gantry rails, forming a rectangular volume approximately 1000 mm × 650 mm × 410 mm. The fixed sensing station, weighing platform, and output bins are arranged within this envelope to reduce motion travel and maintain short cycle times. Objects are transported from the pick region to the sensing location, weighed and classified, and then routed to the appropriate disposal zone.

## Design Specifications

### CAD Drawings

All dimensions are in millimeters. The drawing scale is 4.9 relative to the robot used in this project.

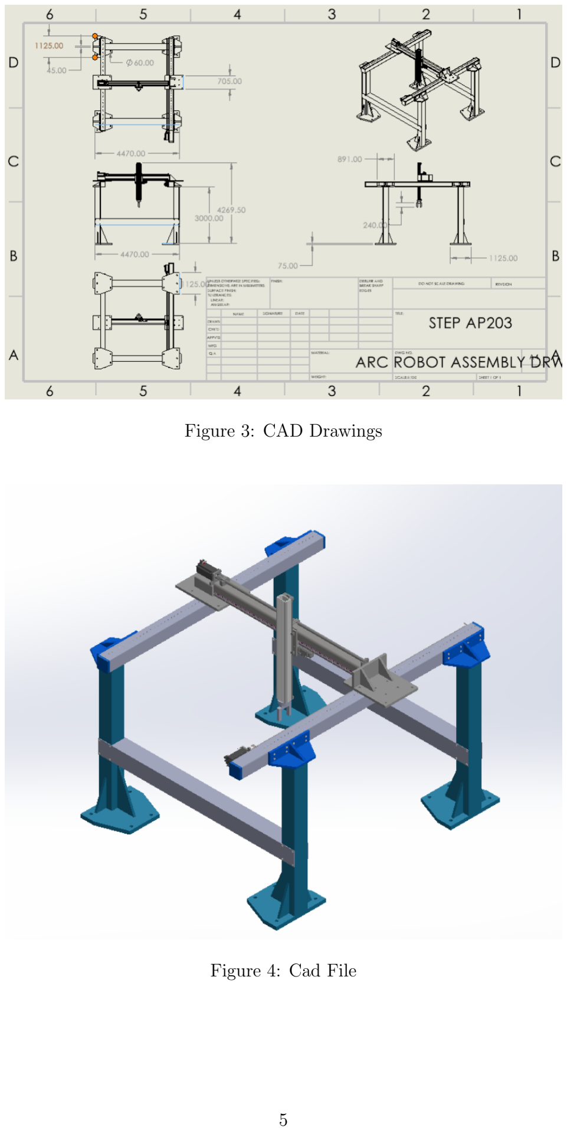
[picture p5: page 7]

Figure 3: CAD Drawings

Figure 4: Cad File

# Part 2: Kinematic Structure

## Robot Joints and Kinematic Structure

The robot is designed as a PPP manipulator, meaning it has three prismatic joints arranged orthogonally. This configuration enables simple translational motion in the three independent directions (X, Y, Z), ensuring that the end-effector can reach any point within a rectangular workspace.

### Reasoning for Design

Three prismatic joints were selected because they provide the minimum degrees of freedom required for full translational positioning in 3D space. The absence of rotational joints simplifies kinematic equations, avoids singularities, and reduces control complexity. This structure is ideal for pick-and-place tasks, material handling, and environments where end-effector orientation is fixed or non-critical.

## Joint Types, Axes, and Limits

- Joint 1 (q1): Prismatic along the Y axis (vertical). Critical due to gravitational load. Typical limits: q1 ∈ [q1,min, q1,max].
- Joint 2 (q2): Prismatic along the X axis (horizontal). Provides lateral positioning. Limits: q2 ∈ [q2,min, q2,max].
- Joint 3 (q3): Prismatic along the Z axis (depth). Provides forward/backward positioning. Limits: q3 ∈ [q3,min, q3,max].

## Forward Kinematic Model

Frame assignments:

- Base frame {0} fixed at the origin.
- Frame {1} translates along Y.
- Frame {2} translates along X.
- Frame {3} translates along Z.
- End-effector frame attached to the gripper.

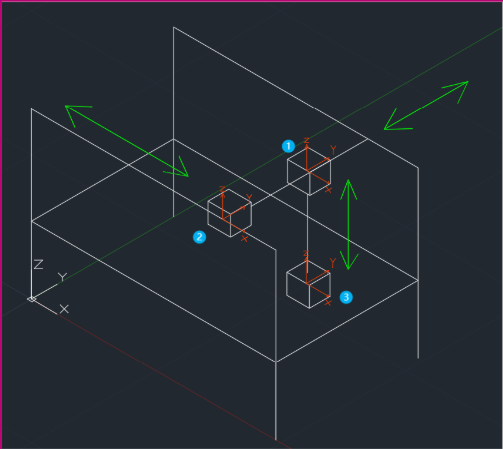
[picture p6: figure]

Figure 5: Schematic Diagram

The end-effector position is simply:

x = q2, | y = q1, | z = q3.

The homogeneous transformation from base to end-effector is:

T0 EE =

1 0 0 q2
0 1 0 q1
0 0 1 q3
0 0 0 1

## Modified DH Parameters

Since this is a PPP robot:

- All twist angles αi = 0.
- All link lengths ai = 0.
- θi values are constant.
- di corresponds to q1, q2, q3.

## Inverse Kinematic Model

The IK is direct:
q1 = yd, | q2 = xd, | q3 = zd.

Joint limits must be satisfied:

qi ∈ [qi,min, qi,max].

Velocity and acceleration limits:

|q˙i

| ≤ q˙i,max, | |q¨i

| ≤ q¨i,max.

Gravity compensation on q1 is recommended:

Fg,1 = meff,1g.

## Extended Inverse Kinematic (IK) Model

For the PPP manipulator (three mutually orthogonal prismatic joints), the end-effector orientation is fixed and motion is purely translational. The IK solution is direct and exact.

### Analytical Solution

Given a desired Cartesian target position (xd, yd, zd) expressed in the base frame:

q1 = yd, | q2 = xd, | q3 = zd.

This yields an analytical, closed-form, globally valid solution with no singularities.

### Joint Priorities and Physical Considerations

- q1 (vertical axis): Most critical due to gravitational load and safety. Requires smoother trajectories and torque/force considerations.
- q2 and q3 (horizontal axes): Dynamically less restrictive; can sustain higher allowable velocities and accelerations.
- Joint priorities may be implemented through weighted objective functions in task-space or joint-space control.

### IK Constraints

Joint limits

q1 ∈ [q1,min, q1,max], | q2 ∈ [q2,min, q2,max], | q3 ∈ [q3,min, q3,max].

The target is feasible only if (xd, yd, zd) lies inside the rectangular parallelepiped defined by these limits.

Velocity and acceleration limits

|q˙i

| ≤ q˙i,max, | |q¨i

| ≤ q¨i,max.

These limits constrain the achievable trajectories during motion execution.

Collision and safety constraints Avoid operating close to hard limits or obstacles; incorporate safe margins when generating trajectories.

### Stability and Robustness Considerations

- Filtering and anti-jitter: Apply smoothing (e.g., low-pass filters or spline interpolation) to avoid abrupt changes caused by noise.
- Soft saturations: Use continuous saturation functions to prevent discontinuities when enforcing limits.
- Task-space control stability: Since J is constant and full rank, a PID or PD controller with feedforward ensures practical stability.
- Gravity compensation: For the vertical joint,

Fg,1 = meff,1 · g,

improves accuracy and reduces steady-state error.

## Differential Kinematic Model

The differential model relates joint velocities to Cartesian velocities of the end-effector. Jacobian:

J =

0 1 0
1 0 0
0 0 1
- , x = [x, y, z]

T
, q = [q1, q2, q3]

T

Velocities:
x˙ = J q,˙ q˙ = J

−1x.˙

Since J is constant and full rank, inversion is stable. Accelerations:
x¨ = J q. ¨
No J˙ terms appear because J is constant.

### Differential Control with Priorities

Weighted task-space mapping may be used with Wx = diag(wx, wy, wz).

### Limits and Stability

Saturate ˙q and ¨q to respect actuator limits. Constant full-rank J ensures numerical stability. Jacobian:

J =

0 1 0
1 0 0
0 0 1

Forward differential kinematics: x˙ = J q.˙

Inverse differential kinematics:
q˙ = J

−1x.˙

Since J is constant and full rank, the inversion is stable.

# Part 3: Workspace Analysis

## Reachable vs Dexterous Workspace

For the PPP robot, the reachable workspace is a rectangular parallelepiped defined by the maximum ranges of all three prismatic joints. Since the robot has no rotational joints, the end-effector orientation is fixed. Therefore, the dexterous workspace coincides with the reachable workspace, but without orientation freedom.
Analytically:
x ∈ [0, Q2 max], | y ∈ [0, Q1 max], | z ∈ [0, Q3 max].

This produces a simple box-shaped workspace.

## Numerical Workspace Plot

A numerical simulation confirms that the analytical workspace matches the computed workspace.

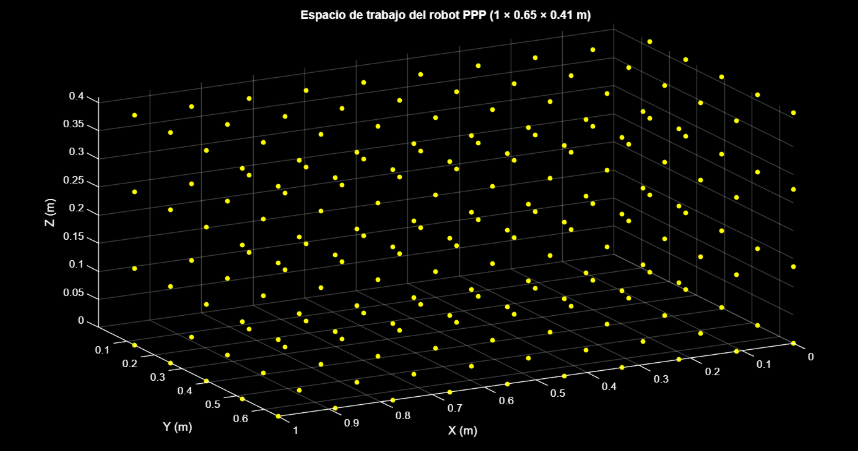
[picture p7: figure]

Figure 6: Workspace Plot

## Jacobian-Based Singularity Identification

The Jacobian is:

J =

0 1 0
1 0 0
0 0 1

Since it is constant and full rank , no singularities occur.

## Classification of Singularities

A PPP robot has no internal singularities. Only mechanical limits at the boundaries restrict motion.

## Workspace Limitations and Implications

- Rectangular workspace limited by joint ranges.
- No orientation freedom.
- Not suitable for orientation-dependent tasks.
- Well-suited for structured pick-and-place applications.
- Handling capacity depends on gripper geometry.
- Limited versatility due to absence of rotational DOF.

# Part 4: Dynamic Analysis and Joint Torque Requirements

## Modeling Method

The dynamic modeling of the PPP Cartesian robot is carried out using a Newton–Euler formulation applied independently to each prismatic axis. Due to the orthogonal and decoupled structure of the Cartesian robot, coupling terms between axes are negligible, allowing each joint to be modeled as a translational mass subjected to inertial, gravitational, frictional, and external forces.
This approach is widely adopted in industrial gantry and Cartesian robots due to its computational simplicity and sufficient accuracy for actuator sizing.

## Full Dynamic Equation

For each prismatic axis, the translational dynamic equation is expressed as:

Ftot = m · a + Fgrav + Ffric + Fext

where:

- m is the equivalent moving mass including payload,
- a is the linear acceleration,
- Fgrav = m · g (only for the Z-axis),
- Ffric = µ · m · g,
- Fext represents external process forces.

The required actuator torque is obtained from the total force using the drive kinematics:
τ =

Ftot · rp

ηdrive

(belt-driven X and Y axes)

τ =

Ftot · L

2π · ηscrew

(ball-screw-driven Z axis)

where rp is the pulley radius, L is the screw lead, and η is the transmission efficiency.

## Gravity Torque Calculation (Z Axis)

For the ball-screw lift axis:

1. Moving mass: mZ = 11.00 kg
2. Gravity force: Fgrav = mZ · g = 11.00 × 9.81 = 107.91 N
3. Acceleration force: Facc,Z = mZ · az = 11.00 × 1.00 = 11.00 N
4. Total axial force: Ftot,Z = 107.91 + 11.00 = 118.91 N
5. Screw torque:

Tscrew =

Ftot,Z · lead

2π · ηscrew

=

118.91 × 0.010
6.283 × 0.90

≈ 0.210 N·m

6. Motor torque (direct drive): Tmotor,Z ≈ 0.210 N·m
7. Screw speed: vz/lead = 0.20/0.010 = 20.0 rev/s = 1200 RPM
8. Angular speed: ω = 2π · 20.0 = 125.66 rad/s
9. Mechanical power: Pmotor,Z = Tmotor,Z · ω ≈ 26.4W
10. With safety factor SFZ = 6: Tdesign,Z = 0.210 × 6 = 1.26 N·m
11. Design-equivalent power: Pdesign,Z = 1.26 × 125.66 ≈ 158.5W

Thus, a servo in the 200–400 W range is appropriate for the Z axis.

## Inertial Torque from Trajectory Motion (X Axis)

For the belt-driven X axis:

1. Acceleration force: Facc,X = mX · axy = 17.00 × 1.00 = 17.00 N
2. Friction force: Ffric,X = µ · mX · g = 0.02 × (17.00 × 9.81) = 3.34 N
3. Total force: Ftot,X = 17.00 + 3.34 = 20.34 N
4. Pulley torque: Tpulley,X = Ftot,X · rp = 20.34 × 0.020 = 0.407 N·m
5. Motor torque: Tmotor,X = 0.407/0.90 ≈ 0.452 N·m
6. Speed: vxy/(2πrp) = 0.50/0.1257 ≈ 3.98 rev/s = 238.7 RPM
7. Angular speed: ω = 25.0 rad/s
8. Mechanical power: Pmotor,X = 0.452 × 25.0 ≈ 11.3W
9. With safety factor SFX = 3: Tpeak,X = 0.452 × 3 = 1.36 N·m

## Inertial Torque from Trajectory Motion (Y Axis)

For the belt-driven Y axis:

1. Acceleration force: Facc,Y = mY · axy = 15.00 × 1.00 = 15.00 N
2. Friction force: Ffric,Y = 0.02 × (15.00 × 9.81) = 2.94 N
3. Total force: Ftot,Y = 15.00 + 2.94 = 17.94 N
4. Pulley torque: Tpulley,Y = 17.94 × 0.020 = 0.359 N·m
5. Motor torque: Tmotor,Y = 0.359/0.90 ≈ 0.399 N·m
6. Speed: same as X axis, 238.7 RPM, ω = 25.0 rad/s
7. Mechanical power: Pmotor,Y = 0.399 × 25.0 ≈ 9.97W
8. With safety factor SFY = 3: Tpeak,Y = 0.399 × 3 = 1.20 N·m

## Payload and External Forces

The payload mass is included in the equivalent moving mass of each axis. No additional external process forces are considered for pick-and-place operation.

### Assumptions

- Payload: mpayload = 5.00 kg
- Extra assembly masses: mz = 6.00 kg (Z carriage + screw + gripper), my = 4.00 kg (Y carriage & structure), mx = 2.00 kg (X extras)
- Linear maximum speeds: vxy = 0.50 m/s (X & Y), vz = 0.20 m/s (Z)
- Accelerations: axy = 1.00 m/s²

, az = 1.00 m/s²

- Pulley effective radius: rp = 0.020 m (20 mm)
- Ball-screw lead: lead = 0.010 m/rev (10 mm per rev)
- Screw efficiency: ηscrew = 0.90
- Drive efficiency (belts/gear): ηdrive = 0.90
- Linear guide friction coefficient: µ = 0.02
- Gravity: g = 9.81 m/s²
- Safety factors: SFXY = 3.0 for X/Y peaks; SFZ = 6.0 for Z (holding + safety)
- Workspace: X = 1.000 m, Y = 0.610 m, Z = 0.410 m

### Notation & Formulas

Facc = m · a, | Ffric = µ · m · g, | Ftot = Facc + Ffric
Tpulley = Ftot · rp, | Tmotor =

Tpulley

ηdrive

Tscrew =

Ftot · lead

2π · ηscrew
rev/s = v
2πrp
, | RPM = rev/s · 60, | ω = 2π · rev/s
P = T · ω, | Tdesign = Tmotor · SF

### Step-by-Step Numeric Calculations

Masses each axis must move:

mZ = mpayload + mz = 5.00 + 6.00 = 11.00 kg

mY = mpayload + mz + my = 5.00 + 6.00 + 4.00 = 15.00 kg

mX = mpayload + mz + my + mx = 5.00 + 6.00 + 4.00 + 2.00 = 17.00 kg

## Maximum Required Joint Torque Determination

From Sections 4.3 and 4.4, the maximum continuous torque requirements are:

Tmotor,X = 0.452 N·m, | Tmotor,Y = 0.399 N·m, | Tmotor,Z = 0.210 N·m

## Safety Factor for Actuator Sizing

Tdesign = Tmax · SF

- For X and Y axis, SF = 3
- For Z axis, SF = 6
Tdesign,X = 1.36 N·m, | Tdesign,Y = 1.20 N·m, | Tdesign,Z = 1.26 N·m

## Torque Tables and Plots

Table 1: Torque requirements and selected motors
Axis | Continuous Torque (N·m) | Design Torque (N·m) | Selected Motor
X Y Z | 0.45 0.40 0.21 | 1.36 1.20 1.26 | 750 W servo 400 W servo 750 W servo

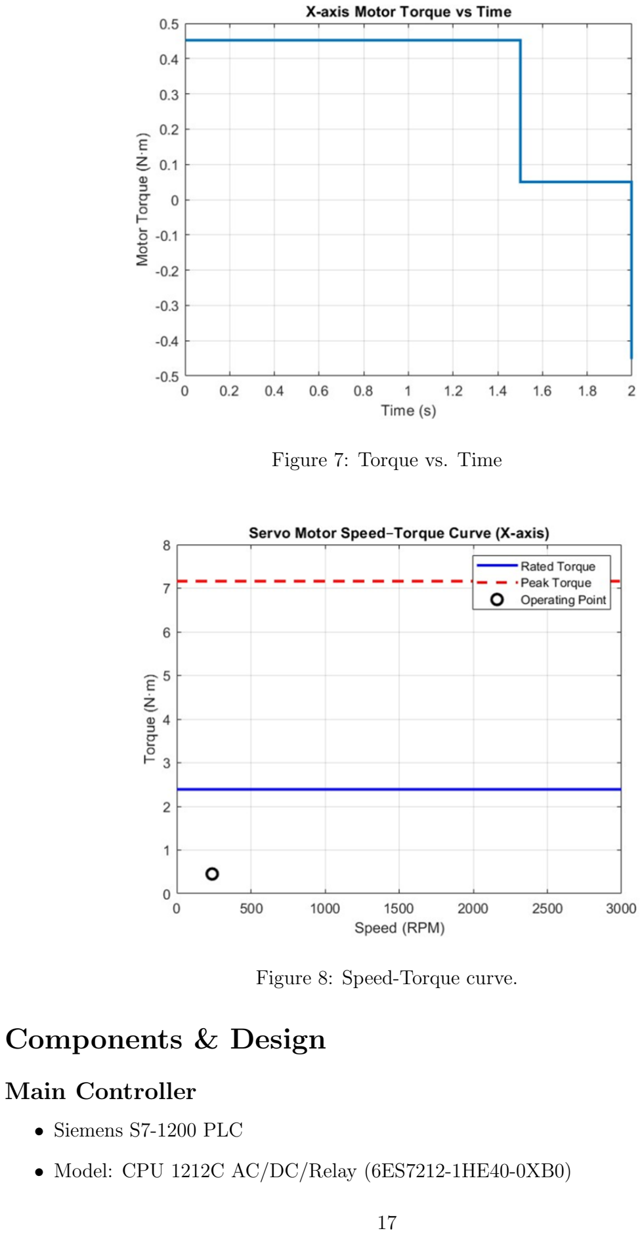
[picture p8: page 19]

Figure 7: Torque vs. Time

Figure 8: Speed-Torque curve.

## Components & Design

### Main Controller

- Siemens S7-1200 PLC
- Model: CPU 1212C AC/DC/Relay (6ES7212-1HE40-0XB0)

- 8 DI, 6 DO, expandable
- Reliable for industrial environment
- Expansion for Stepper/Servo Control (PTO Outputs)
- Siemens Signal Board SB 1231 (if extra AI required)
- Siemens Pulse-train module not required → CPU1212C already supports PTO up to 100 kHz

### Servo Motors + Drivers (PPP Axes)

Payload 5 kg + 1 m horizontal travel requires servo motors, not steppers.

- X Axis (1 m travel) Servo motor: Delta ECMA-C20807RS (750 W, 3000 rpm) Driver: Delta ASDA-B2 series (Model: ASD-B2-0721-B) Transmission: HTD 5M belt, 25 mm wide OR ballscrew SFU1610
- Y Axis (1 m travel) Servo motor: Delta ECMA-C20604RS (400 W) Driver: Delta ASD-B2-0421-B (400 W driver) Transmission: HTD 5M belt, 20–25 mm width
- Z Axis (0.8–1 m vertical travel) Servo motor: Delta ECMA-C20807RS (750
W) Driver: Delta ASD-B2-0721-B Transmission: Ballscrew SFU1610 with BK/BF supports + linear guides

### Linear Motion Components

- Linear Guides: Hiwin HGR20 rails (20 mm width)
- Blocks: HGW20CC (4 per axis)
- Ballscrews: SFU1610 (16 mm dia, 10 mm pitch) for Z; SFU1605 or HTD 5M belt drive for X & Y

### Sensors for Material Classification

- Metal Detection: Inductive sensor LJ12A3-4-Z/BX, PNP Normally Open, 10–30 VDC
- Plastic vs Paper Detection: Capacitive sensor LJC18A3-B-Z/BX, PNP Normally Open, 10–30 VDC
- Weight Measurement: Load cell 5 kg aluminum plate, amplifier Waveshare 0–10 V output, connected to PLC AI0

### Gripper (Pneumatic)

- Parallel Pneumatic Gripper: SMC MHZ2-20D
- Solenoid Valve: SMC SY3120-5LZD-01, 24 VDC, 3-way single solenoid
- Pneumatic Air Preparation: SMC AF20-N02 (filter), SMC AR20-N02 (regulator)

### Power Supply System

- For PLC, sensors, valves (24 VDC bus): Meanwell LRS-350-24, 24 V, 14.6 A
- For servo drives (48 VDC bus): Meanwell RSP-750-48, 48 V, 60 A
- For load cell amplifier: same 24 V bus (accepts 12–24 V)

### Safety Components

- Main Breaker: Schneider GV2-ME10 (adjustable 6–10 A)
- Emergency Stop: Schneider XALK178 mushroom E-stop
- Fuses: 5×20 mm fuse holders, 3A fuse for 24V logic, 10–15A fuse for servo power input
- Surge & Noise Protection: Ferrite cores on all servo cables, EMI filter Schaffner FN2070-10-06

### Cables & Wiring

- Servo Motor Power Cables: 4-core shielded, 2.5 mm² (750 W), 1.5 mm² (400 W), length 8–10 m per axis
- Encoder/Signal Cables: 6-core shielded twisted pair, 0.5–0.75 mm², 10 m per axis
- Sensor Cables: 3-wire shielded, 0.5 mm², 5–10 m
- PLC Wiring: Single core 0.75 mm² for DO/DI and 24V distribution

### Electrical Enclosure Components

- Metal enclosure 600×400×200 mm (steel)
- DIN rails (2× 350 mm)
- Cable ducts
- 24VDC terminal blocks (Weidm¨uller)
- Grounding bar
- Cooling fan 120 mm + filter

## Wiring Diagram

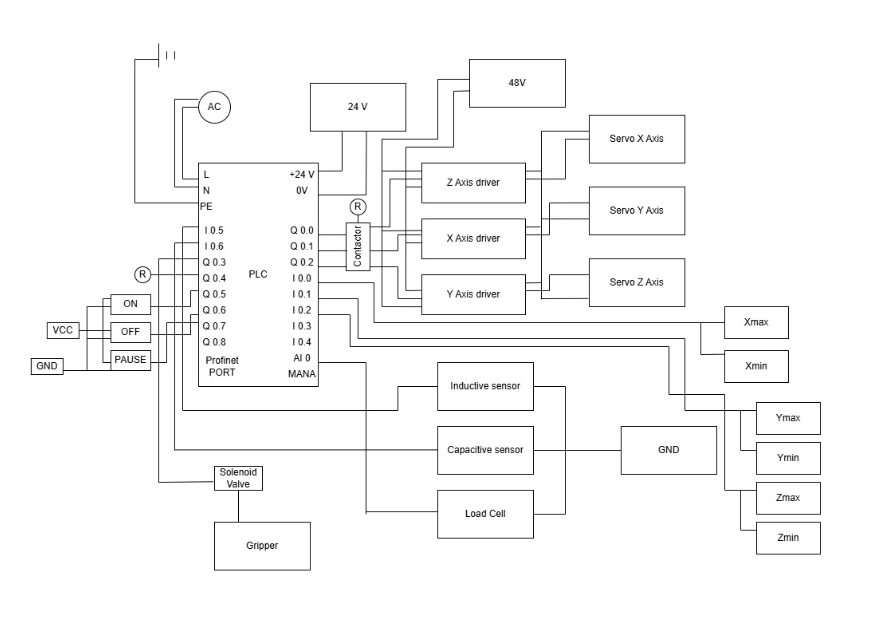
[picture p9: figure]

Figure 9: Wiring Diagram.

## PLC Configuration

### DI Tags

- I0.0 | X MINMAX
- I0.1 | Y MINMAX
- I0.2 | Z MINMAX
- I0.5 | METAL IND
- I0.6 | CAP HIGH

### DO Tags

- Q0.0 | SERVO ENABLE X
- Q0.1 | SERVO ENABLE Y
- Q0.2 | SERVO ENABLE Z
- Q0.3 | GRIPPER OC
- Q0.4 | COIL CONTACTOR

- Q0.5 | TOWER RED
- Q0.6 | TOWER YELLOW
- Q0.7 | TOWER GREEN

### AI Tag

- AI0 | WEIGHT mA | (scale 4–20 mA → 0..FULL SCALE grams)

### PROFINET Drive Tags

DriveX

- DriveX.ControlWord
- DriveX.TargetPosition
- DriveX.TargetVelocity
- DriveX.StatusWord
- DriveX.ActualPosition
- DriveX.ErrorCode

DriveY

- DriveY.ControlWord
- DriveY.TargetPosition
- DriveY.TargetVelocity
- DriveY.StatusWord
- DriveY.ActualPosition
- DriveY.ErrorCode

DriveZ

- DriveZ.ControlWord
- DriveZ.TargetPosition
- DriveZ.TargetVelocity
- DriveZ.StatusWord
- DriveZ.ActualPosition
- DriveZ.ErrorCode

## PLC Logic Chart

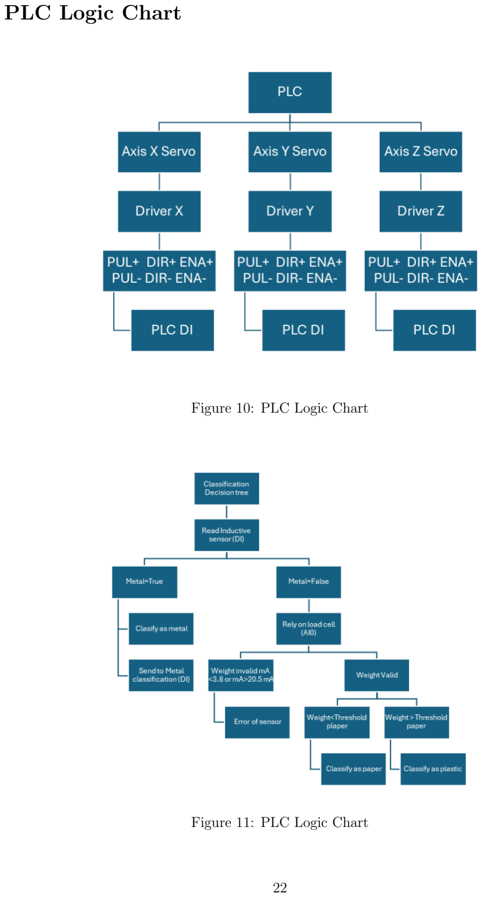
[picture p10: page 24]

Figure 10: PLC Logic Chart

Figure 11: PLC Logic Chart

# Part 5: Trajectory Generation Techniques

## Project Overview

A PPP robot was implemented in MATLAB and Simulink. The folder PPP Robot GUI contains the key files:

- ppp fk.m: forward kinematics
- plot ppp.m: visualization
- animate pick and place.m: joint-space trajectory example
- ppp dynamics.m: simplified dynamics
- gui ppp sim.m: real-time control GUI

## Joint-Space Trajectories

Interpolated trajectories in q1, q2, q3 were implemented in animate pick and place.m, producing non-linear Cartesian paths. MATLAB animate pick and place.m

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

T = [eye (3) , [ x ; y ; z ]; 0 0 0 1]; end

Listing 1: MATLAB ppp fk.m

## Task-space trajectories

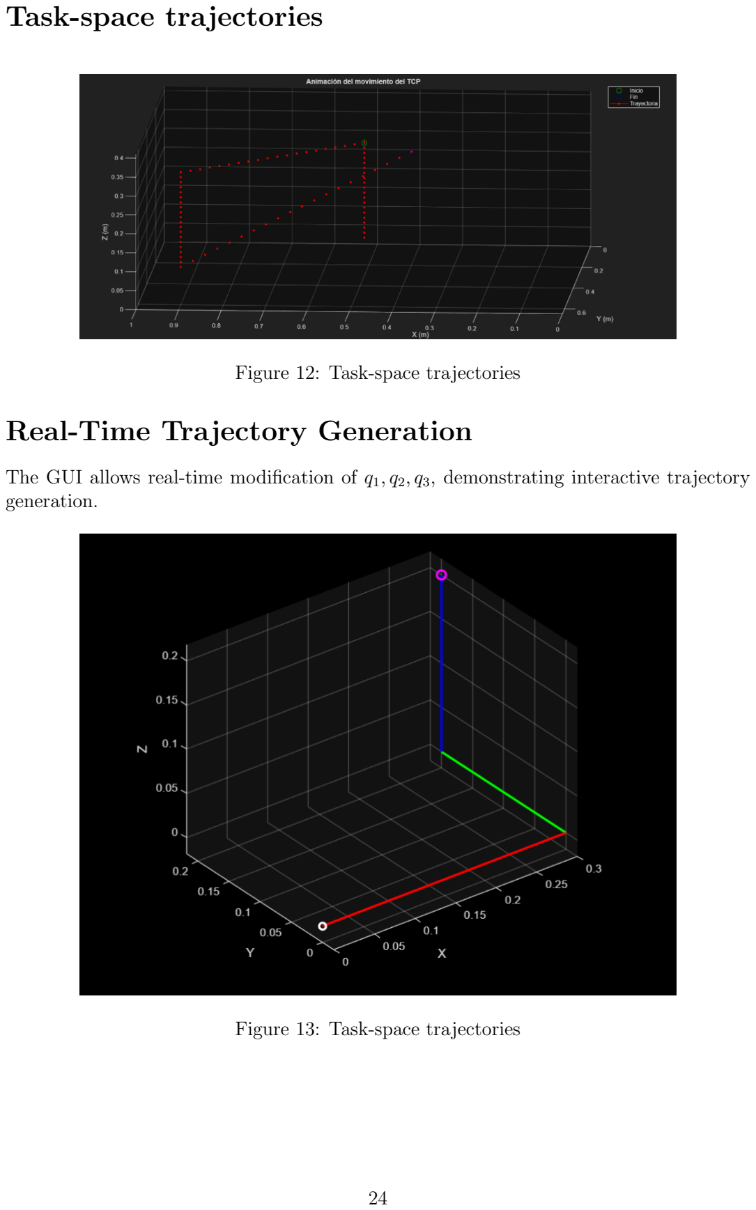
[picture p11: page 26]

Figure 12: Task-space trajectories

## Real-Time Trajectory Generation

The GUI allows real-time modification of q1, q2, q3, demonstrating interactive trajectory generation.

Figure 13: Task-space trajectories

function gui_ppp_sim ()
f = figure (’Name ’,’Simulador Robot
PPP ’,’Color ’,’k’,’Position ’ ,[100 100 800 600]) ;

% Sliders para q1 , q2 , q3
uicontrol (f ,’Style ’,’text ’,’String ’,’q1 (Y vertical )’ ,... ’Position ’ ,[20 550 100
20] , ’ ForegroundColor ’,’w’,’ BackgroundColor ’,’k’) ;
s1 =
uicontrol (f ,’Style ’,’slider ’,’Min ’ ,0 ,’Max ’ ,1 ,’Value ’ ,0.2 ,... ’Position ’ ,[130 550 200 20] , ’Callback ’, @update_plot ) ;

uicontrol (f ,’Style ’,’text ’,’String ’,’q2 (X horizontal )’ ,... ’Position ’ ,[20 520 100
20] , ’ ForegroundColor ’,’w’,’ BackgroundColor ’,’k’) ;
s2 =
uicontrol (f ,’Style ’,’slider ’,’Min ’ ,0 ,’Max ’ ,1 ,’Value ’ ,0.5 ,... ’Position ’ ,[130 520 200 20] , ’Callback ’, @update_plot ) ;

uicontrol (f ,’Style ’,’text ’,’String ’,’q3 (Z profundidad )’ ,... ’Position ’ ,[20 490 100
20] , ’ ForegroundColor ’,’w’,’ BackgroundColor ’,’k’) ;
s3 =
uicontrol (f ,’Style ’,’slider ’,’Min ’ ,0 ,’Max ’ ,1 ,’Value ’ ,0.3 ,... ’Position ’ ,[130 490 200 20] , ’Callback ’, @update_plot ) ;

% B o t n de a n i m a c i n
uicontrol (f ,’Style ’,’pushbutton ’,’String ’,’Animar Pick & Place ’ ,...
’Position ’ ,[600 550 150 30] , ’Callback ’,@ ( src , event ) animate_pick_and_place () ) ;

% Ejes de v i s u a l i z a c i n
ax = axes (’Parent ’,f ,’Position ’ ,[0.4 0.1 0.55 0.75]) ; set( ax ,’Color ’,’k’) ;
view (3) ; axis equal ; grid on ;
xlabel (’X’) ; ylabel (’Y’) ; zlabel (’Z’) ;

% F u n c i n de a c t u a l i z a c i n
function update_plot (~ ,~)
q = [ s1 . Value ; s2 . Value ; s3 . Value ]; axes ( ax ) ;
plot_ppp (q , ’c’) ;
end

update_plot () ;
end

Listing 2: MATLAB gui ppp sim.m function plot_ppp (q , color )
% Visualiza el robot PPP en c o n f i g u r a c i n q T = ppp_fk ( q ) ;
pos = T (1:3 ,4) ;

clf; hold on ; axis equal ;
set(gcf ,’Color ’,’k’) ; % fondo negro xlabel (’X’) ; ylabel (’Y’) ; zlabel (’Z’) ; view (3) ; grid on ;

% Ejes base
plot3 (0 ,0 ,0 , ’wo ’,’MarkerSize ’ ,6 ,’LineWidth ’ ,2) ;
% Trayectoria de cada eje
plot3 ([0 q (2) ] , [0 0] , [0 0] , ’r’, ’LineWidth ’, 2) ; % eje Y X
plot3 ([ q (2) q (2) ] , [0 q (1) ] , [0 0] , ’g’, ’LineWidth ’, 2) ; %
eje Z | Y
plot3 ([ q (2) q (2) ] , [ q (1) q (1) ] , [0 q (3) ] , ’b’, ’LineWidth ’,
2) ; % eje X | Z

% End - effector
plot3 ( pos (1) , pos (2) , pos (3) , ’mo ’, ’MarkerSize ’, 8 , ’LineWidth ’, 2) ;
end

Listing 3: MATLAB plot ppp.m

## Task-Space Trajectories

Using ppp fk.m, Cartesian paths (x, y, z) are mapped into joint space for linear or curved workspace paths.

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

T = [eye (3) , [ x ; y ; z ]; 0 0 0 1]; end

Listing 4: MATLAB ppp fk.m

## Trajectory Constraints

Velocity, acceleration, and workspace limits can be enforced during interpolation.

function tau = ppp_dynamics (q , dq , ddq , m )
% Modelo d i n m i c o simplificado
g = 9.81;
M = diag ( m ) ; % matriz de inercia
G = [ m (1) * g ; 0; 0]; % gravedad solo en eje vertical C = zeros (3 ,1) ; % sin Coriolis

tau = M * ddq + C + G ;
end

Listing 5: MATLAB ppp dynamics.m

## Discussion of Methods

- Joint-space: simple, but produces curved Cartesian paths.
- Task-space: intuitive, but requires IK.
- Real-time: ideal for testing and interactive control.

# Part 6: Conclusion

## Overall System Evaluation

The Automated Recycling Classifier (ARC) system successfully demonstrates the feasibility of using a low-cost PPP Cartesian robot combined with non-vision sensors for material classification in a benchtop recycling application. The integration of inductive sensing, capacitive dielectric measurement, and load-cell-based mass evaluation provides a sensor fusion approach capable of distinguishing metal, plastic, and paper with acceptable reliability under controlled conditions. The use of a fixed sensing station proved critical in reducing variability caused by distance, grounding effects, vibration, and dynamic loading. This design choice resulted in improved repeatability and signal consistency across classification cycles. The PPP gantry configuration offered mechanical simplicity, predictable kinematics, and ease of control, aligning well with the project objectives of affordability, modularity, and ease of implementation. While the system is not intended for industrial-scale throughput or complex material mixtures, it effectively fulfills its role as a compact automated sorting demonstrator and educational prototype.

## Recommendations

- Implement signal filtering and averaging techniques to reduce sensor noise and improve capacitive and load cell measurement stability.
- Introduce calibration routines for the capacitive sensor and load cell to compensate for environmental variations such as humidity and temperature.
- Improve mechanical isolation of the weighing platform to minimize vibration-induced measurement errors.
- Explore adaptive thresholding or simple machine learning classifiers to enhance plastic–paper differentiation.
- Consider modular mechanical design upgrades to allow easy scaling of workspace dimensions or payload capacity.

## Summary of Results

- Reliable execution of autonomous pick–classify–place cycles within the defined workspace was achieved.
- Metal objects were consistently detected using the inductive proximity sensor.

- Plastic and paper materials were differentiated using a combination of dielectric sensing and mass measurement.
- Stable and repeatable classification was demonstrated at a fixed sensing station.
- Effective integration of low-cost, non-vision sensors was achieved without compromising system functionality.

## Suitability for Intended Application

The ARC platform is well suited for its intended application as a benchtop automated recycling classifier and proof-of-concept system. It addresses limitations associated with manual sorting by improving consistency, reducing human involvement, and enabling repeatable material classification using affordable hardware. Although the system is not designed for high-speed industrial recycling lines or complex composite materials, it is highly appropriate for educational and research environments, small-scale recycling demonstrations, and prototype development or sensor evaluation platforms. Its low cost, compact footprint, and straightforward control architecture make it a practical solution for controlled sorting scenarios.

## Final Design Justification

The final ARC system design is justified by its strong alignment with the project objectives of affordability, simplicity, and functional effectiveness. The use of a PPP Cartesian manipulator ensures predictable motion, ease of simulation, and low mechanical complexity. Employing non-vision sensors significantly reduces system cost and computational requirements while maintaining acceptable classification performance under controlled conditions. The fixed sensing station design addresses key challenges related to measurement repeatability and sensor stability, enabling reliable sensor fusion. Overall, the final design represents a well-balanced compromise between performance, cost, and technical complexity, making it a suitable and defensible solution for automated recycling classification at the prototype level.

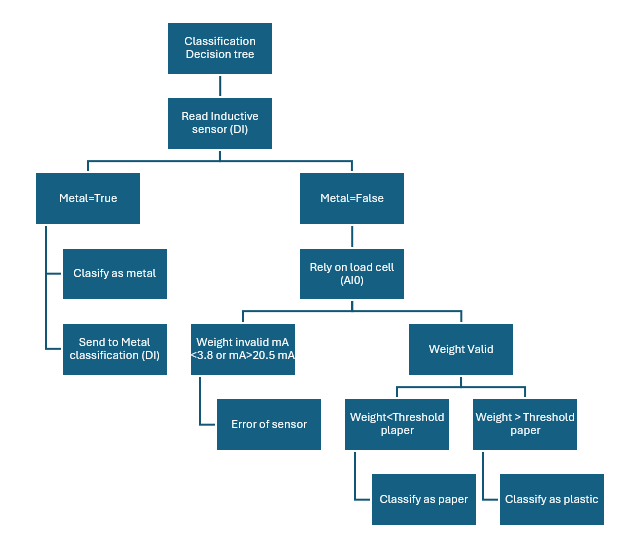
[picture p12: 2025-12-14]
INTRODUCTION TO ROBOTICS/Electrical/Sequence logic.png

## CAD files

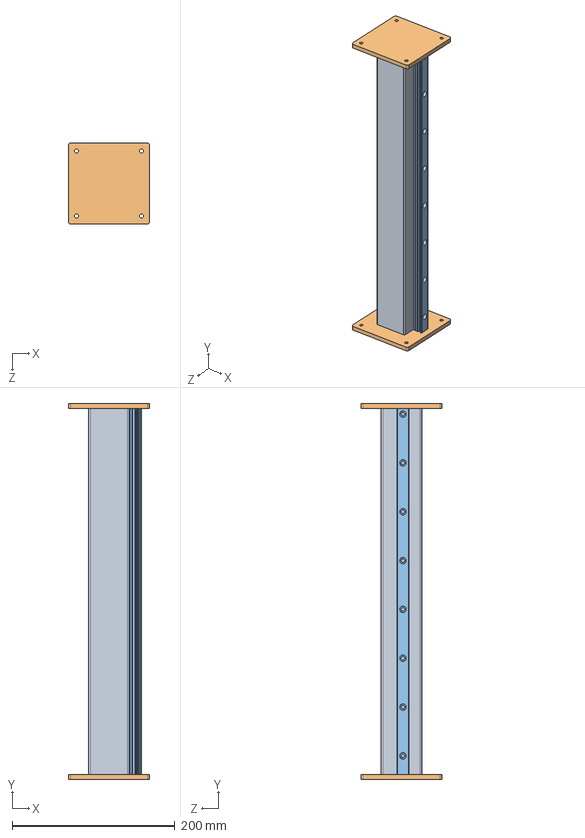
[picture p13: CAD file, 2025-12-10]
INTRODUCTION TO ROBOTICS/CAD Files/CAD robots Parts/Part 27.SLDASM
100.0 x 462.0 x 100.0 mm
hop 50x50x3xL480
bich3 x 2
ray truot 450-1

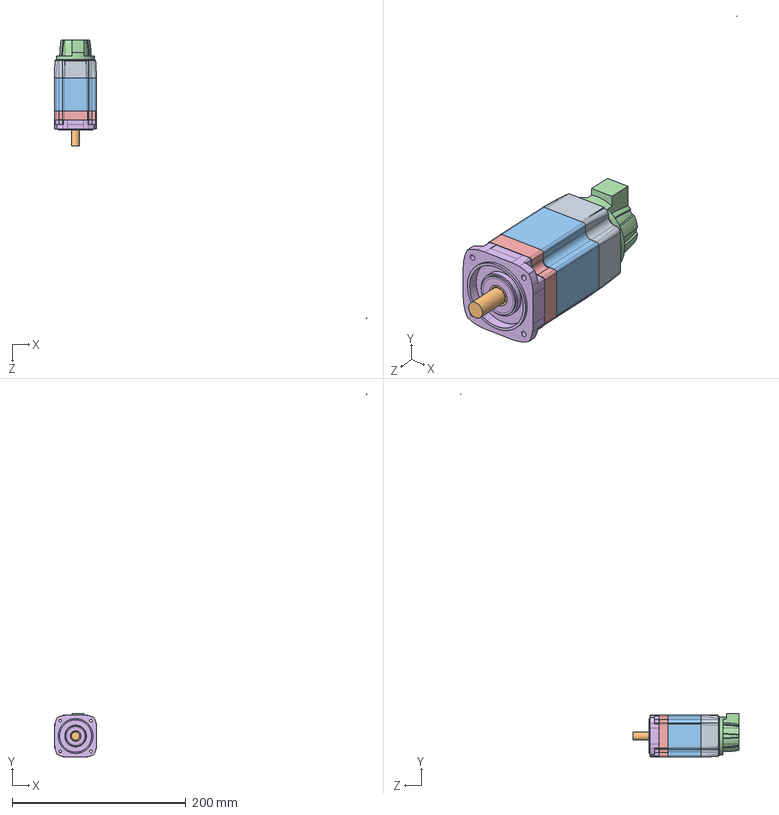
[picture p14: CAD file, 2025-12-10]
INTRODUCTION TO ROBOTICS/CAD Files/CAD robots Parts/part 43.SLDASM
359.2 x 417.7 x 320.5 mm

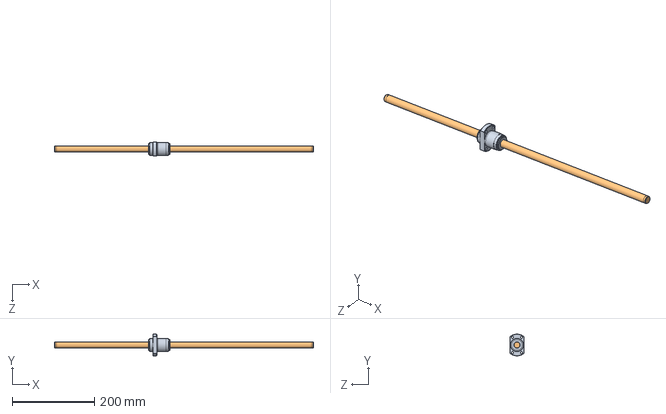
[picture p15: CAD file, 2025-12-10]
INTRODUCTION TO ROBOTICS/CAD Files/CAD robots Parts/part 26.SLDASM
630.0 x 53.0 x 33.0 mm
nut-620
shaft-620

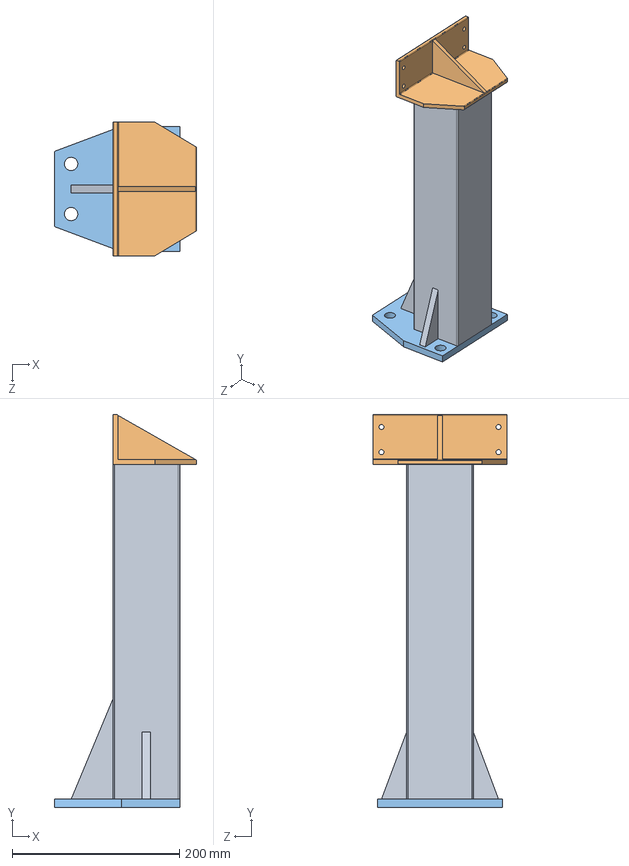
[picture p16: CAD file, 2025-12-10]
INTRODUCTION TO ROBOTICS/CAD Files/CAD robots Parts/part 39.SLDASM
170.0 x 470.0 x 160.0 mm
hop 80x80x4xL400
bich1
bichchan

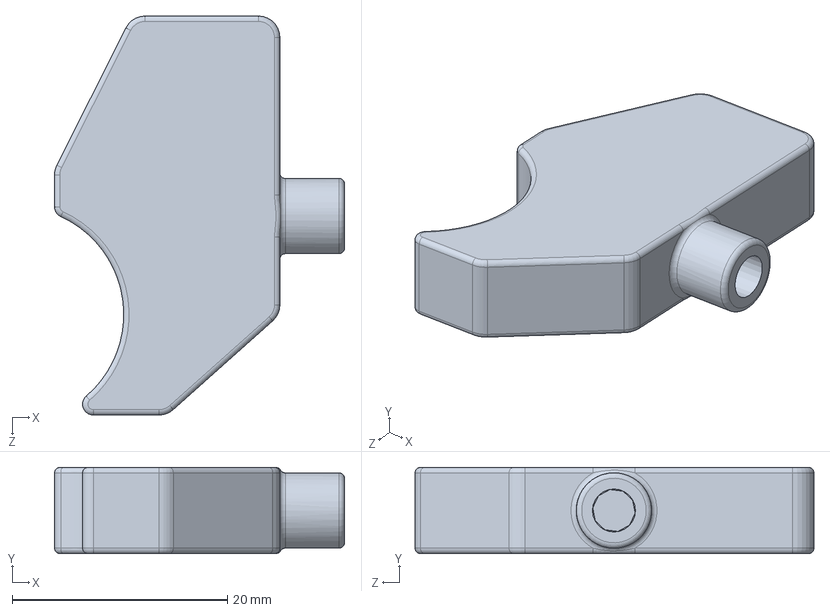
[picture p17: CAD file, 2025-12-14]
INTRODUCTION TO ROBOTICS TUTORIAL/aligment/aligment_block_A2.SLDPRT
27.0 x 8.00 x 37.1 mm

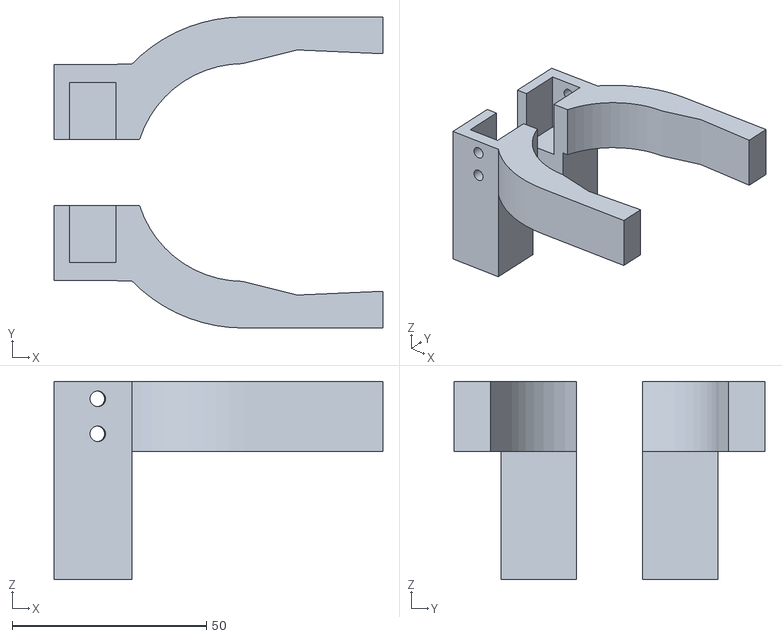
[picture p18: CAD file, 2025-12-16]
INTRODUCTION TO ROBOTICS TUTORIAL/Task03/Cad Files/BigGripper10.0.STL
84.6 x 80.0 x 51.0

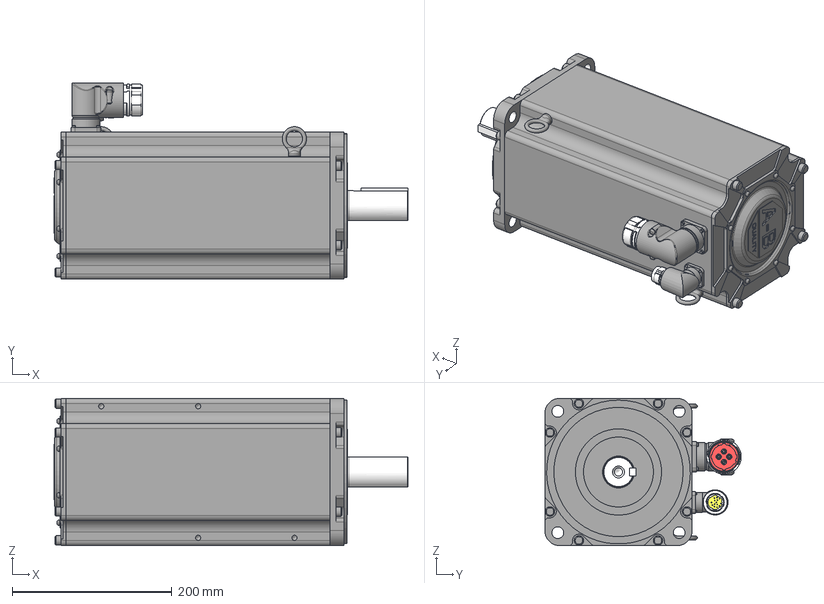
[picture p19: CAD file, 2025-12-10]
INTRODUCTION TO ROBOTICS/CAD Files/CAD robots Parts/Part 11.stp
443.5 x 246.1 x 184.7 mm
Rockwell Automation-MPL-x660x-xJ74AA_MPL-6xx-Body_660-BRAKE
Rockwell Automation-MPL-x660x-xJ74AA_MPL-6xx-Shaft-Key_660-shaft-keye d-BRAKE
Rockwell Automation-MPL-x660x-xJ74AA_MPL-6xx-Power Connector-M40
Rockwell Automation-MPL-x660x-xJ74AA_MPL-6xx-Encoder Connector
Rockwell Automation-MPL-x660x-xJ74AA_MPL-6xx-Eyebolt x 2

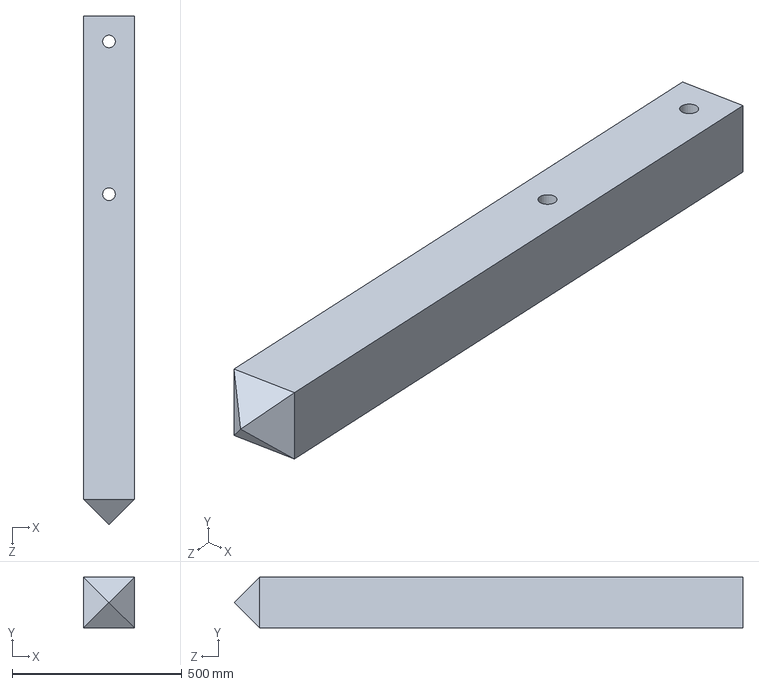
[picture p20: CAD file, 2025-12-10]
INTRODUCTION TO ROBOTICS/CAD Files/CAD robots Parts/part 41.SLDPRT
150.0 x 150.0 x 1500.0 mm

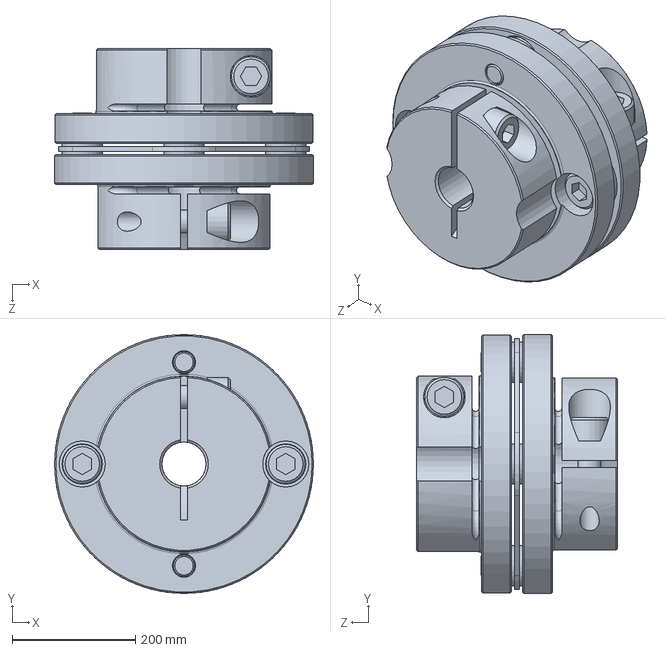
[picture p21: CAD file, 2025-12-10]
INTRODUCTION TO ROBOTICS/CAD Files/CAD robots Parts/part 46.SLDPRT
420.0 x 420.0 x 325.5 mm

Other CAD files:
INTRODUCTION TO ROBOTICS TUTORIAL/Task01/PIckiplase/PIckiplase.obj
INTRODUCTION TO ROBOTICS TUTORIAL/Task02/Stacking/Stacking.obj
INTRODUCTION TO ROBOTICS TUTORIAL/Task03/Task3/stackingg.obj
INTRODUCTION TO ROBOTICS TUTORIAL/Task01/PIckiplase/stackingg.obj
INTRODUCTION TO ROBOTICS TUTORIAL/Task02/Stacking/TCPIPdemo.obj
INTRODUCTION TO ROBOTICS TUTORIAL/Task03/Cad Files/BigGripper.SLDPRT
INTRODUCTION TO ROBOTICS TUTORIAL/Task03/Task3/Task3.obj
INTRODUCTION TO ROBOTICS TUTORIAL/Task02/Stacking/stackingg.obj
INTRODUCTION TO ROBOTICS TUTORIAL/Task03/Task3/TCPIPdemo.obj
INTRODUCTION TO ROBOTICS TUTORIAL/aligment/aligment_block_A2.STL
INTRODUCTION TO ROBOTICS/CAD Files/CAD robots Parts/Part 10.SLDPRT
INTRODUCTION TO ROBOTICS/CAD Files/CAD robots Parts/Part 14.SLDPRT
INTRODUCTION TO ROBOTICS/CAD Files/CAD robots Parts/Part 15.stp
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

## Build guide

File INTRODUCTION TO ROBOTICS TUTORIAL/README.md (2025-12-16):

<h1>Task 1 <h1>



We use a metal piece to create a wall to perform the alignment procedure




<h1>Task 2<h1>  



<h1>HMI<h1>  



<h1>Task 3<h1>


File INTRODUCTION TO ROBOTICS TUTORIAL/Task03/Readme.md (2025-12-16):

# Task3

This is about serving a traditional Paraguayan Tea the "Terere"





# Gripper Set



# We modify the monture to can use the big gripper



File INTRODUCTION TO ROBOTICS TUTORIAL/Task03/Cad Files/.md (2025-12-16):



Figure 1. CAD File

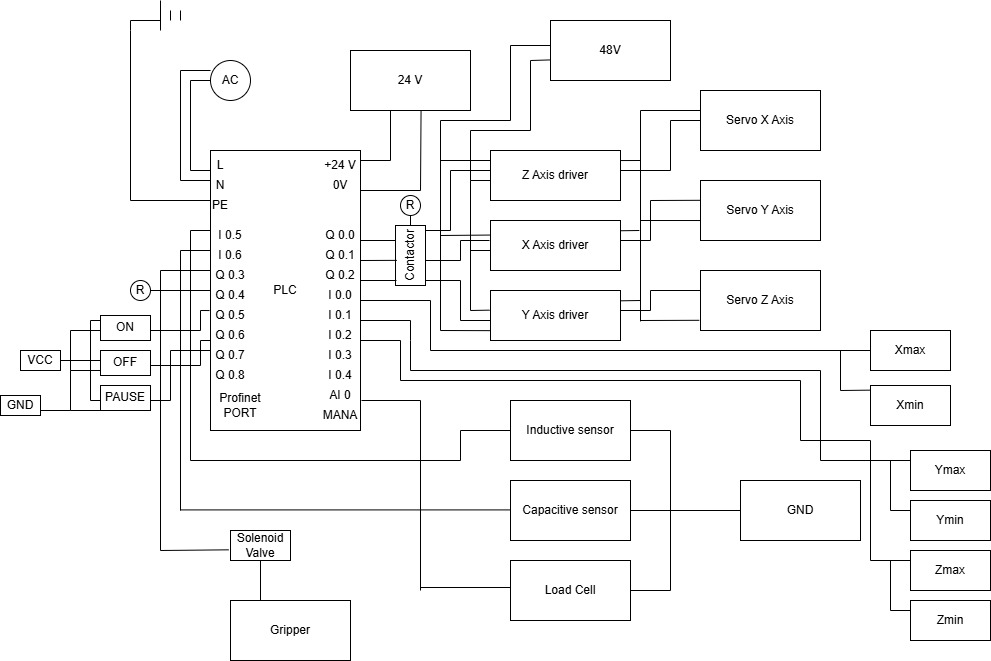
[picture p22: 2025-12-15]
INTRODUCTION TO ROBOTICS/Electrical/Wiring diagram .jpg

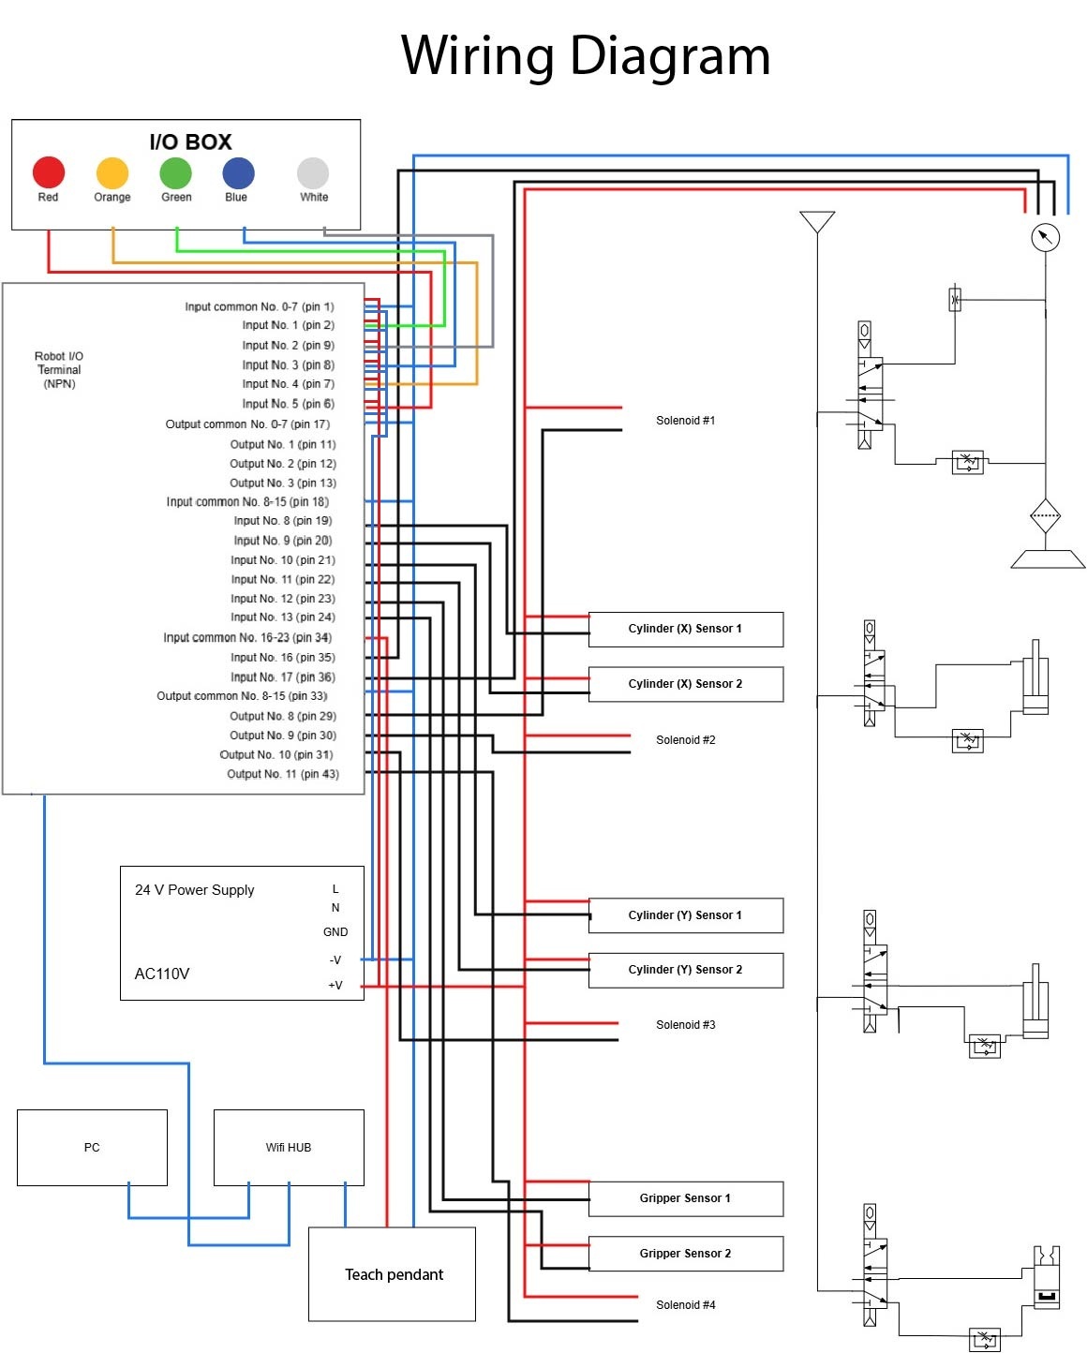
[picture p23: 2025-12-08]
INTRODUCTION TO ROBOTICS TUTORIAL/IO/IO Diagram A2 team v3.jpg

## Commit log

2025-11-30 task 3
    [garratask3.SLDPRT]
2025-12-06 Create No confirmado Codigo con IO para probar
2025-12-10 Create CAD parts of the robot
2025-12-10 Create CAD robots Parts
2025-12-14 Add torque calculations and electrical design section
2025-12-14 Expand Readme with modeling method and assumptions
    Added detailed modeling method and assumptions for torque calculations and electrical design.
2025-12-14 Rename Torque calc.png to Torque Calculations Table
2025-12-14 Rename Torque Calculations Table to Torque Calculations Table.jpg
2025-12-14 Rename wir.jpg to Brief Wiring diagram.jpg
2025-12-14 Add electrical components list for robotics project
    Added a comprehensive list of electrical components and specifications for the robotics project, including controllers, motors, sensors, and safety components.
2025-12-15 Rename Wiring diagram ppp (1).jpg to Wiring diagram .jpg
2025-12-16 Rename .md to Ilustration CAD
2025-12-16 Rename Ilustration CAD to Ilustration CAD.md
